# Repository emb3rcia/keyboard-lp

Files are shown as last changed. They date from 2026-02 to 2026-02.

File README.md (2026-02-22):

# keyboard-lp

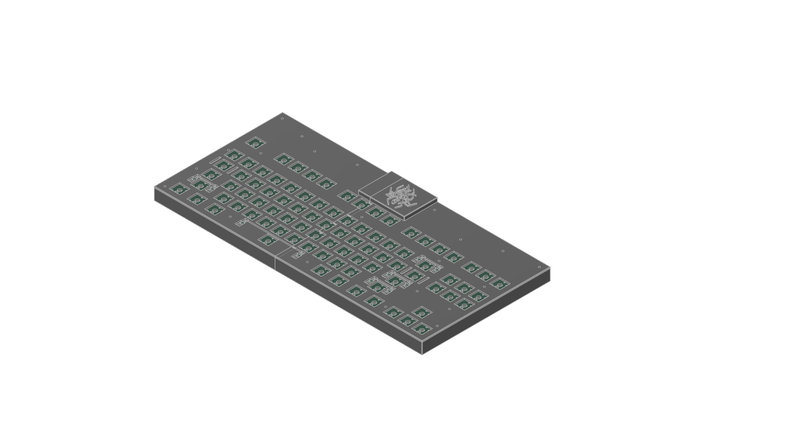
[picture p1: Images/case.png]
case


## Description

It is my first low-profile keyboard, and first per-key GPIO keyboard. It features 2 USB ports - one for communication with PC and one for power for LEDs, per-key LED backlight and full n-key rollover!

## Why i made this project

I like making keyboards, it is my second keyboard i designed and it is very fun. I also want to use LP keyboard, but i dont have budget to buy ready-to-use one.

## What i learned

Mainly i learned even more about tight connection layout on PCB, as with per-key GPIO i needed to connect each key to its individual pin on MCU.

# Photos

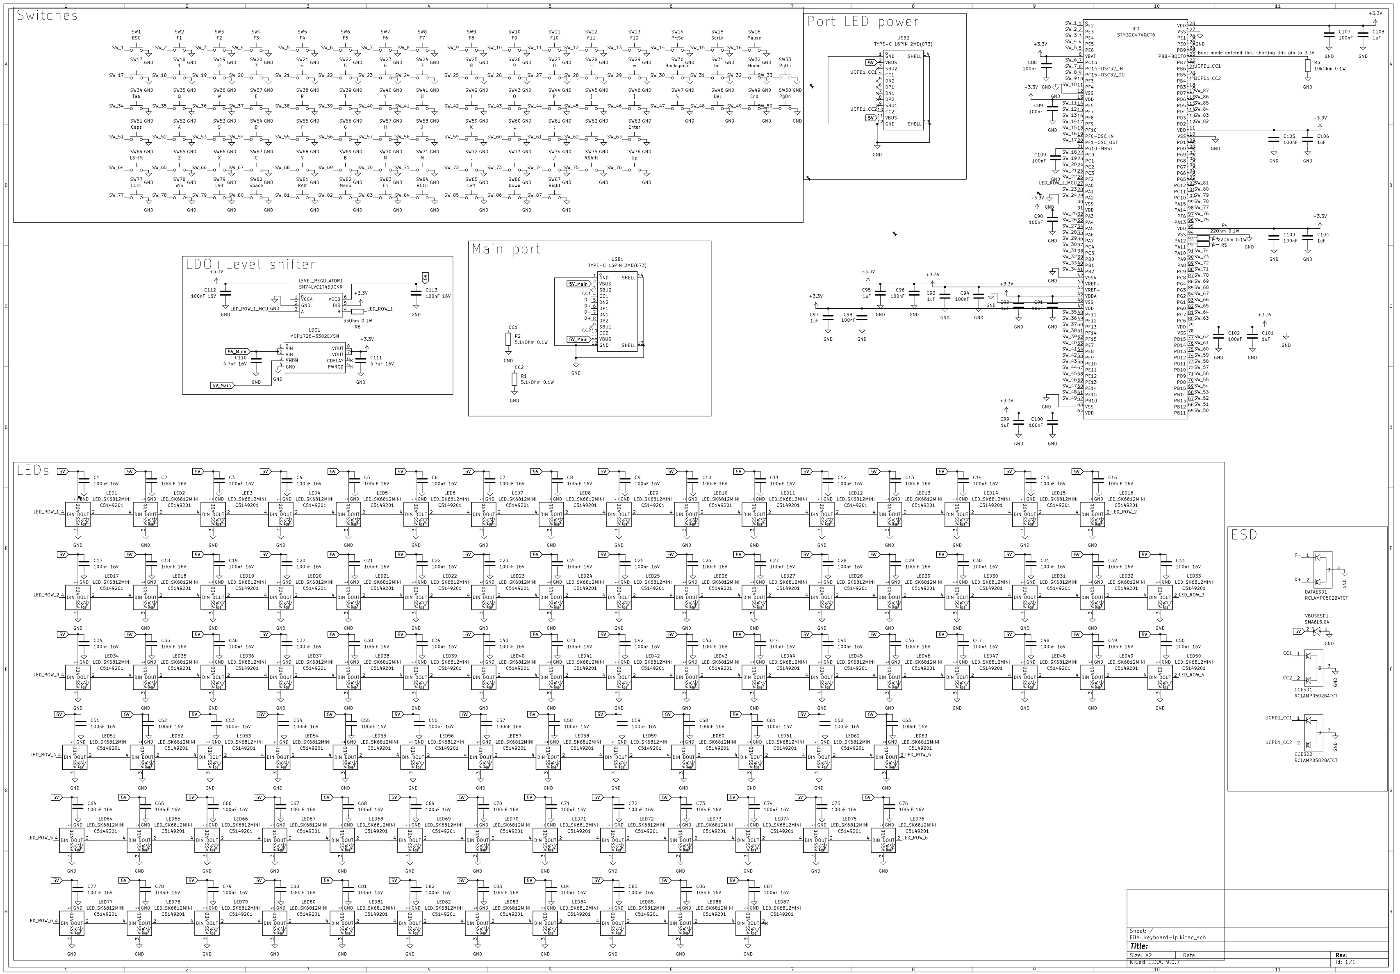
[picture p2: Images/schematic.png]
schematic


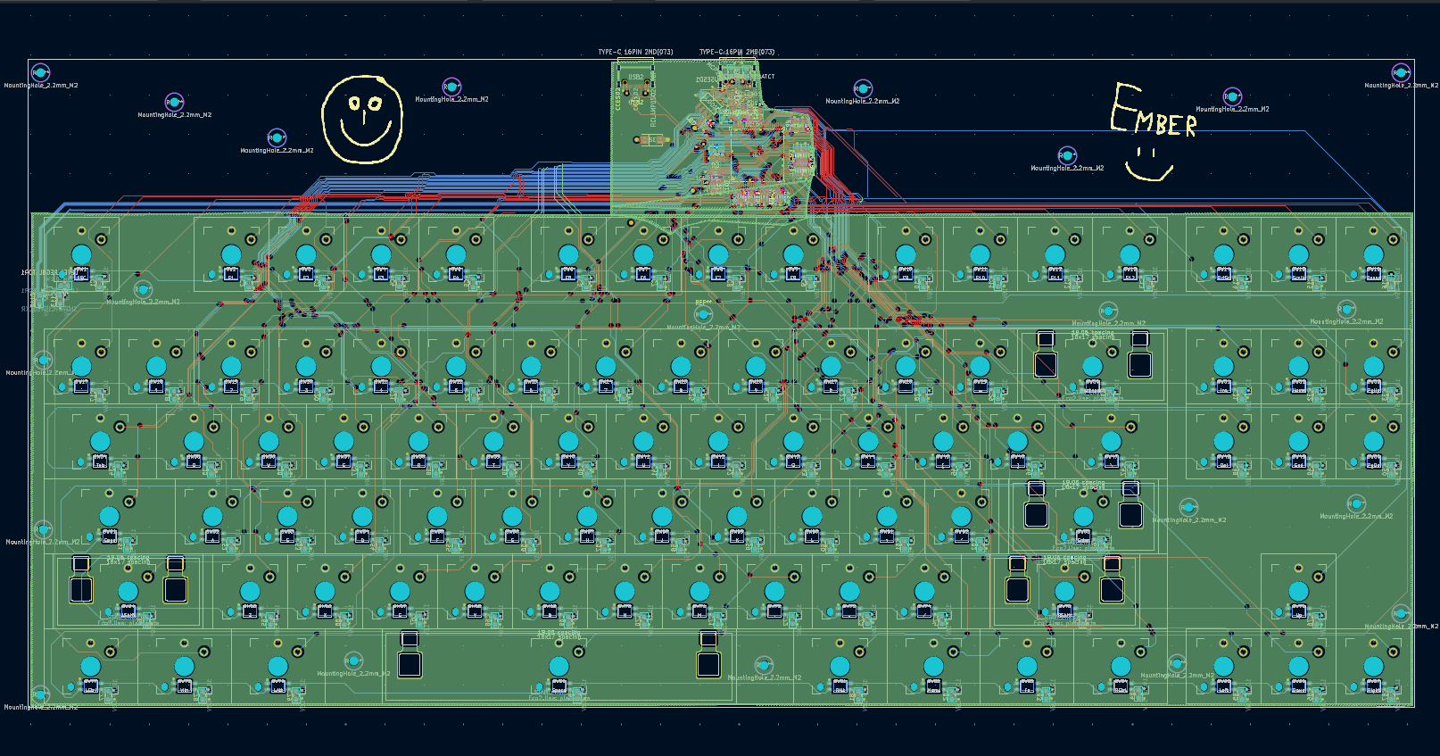
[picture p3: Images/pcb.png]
PCB


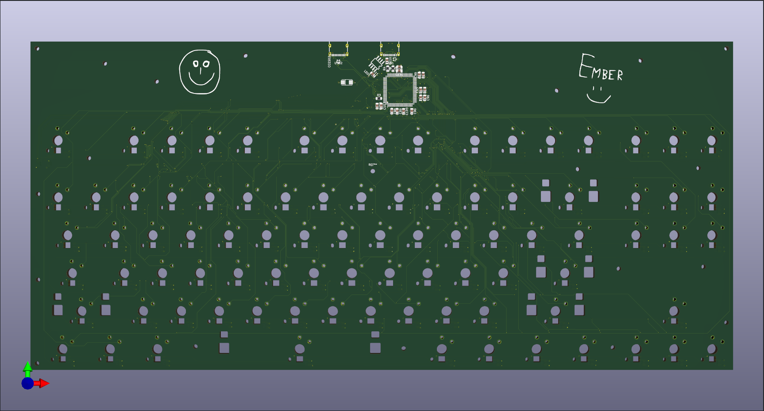
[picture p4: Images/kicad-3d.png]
kicad-3d


case

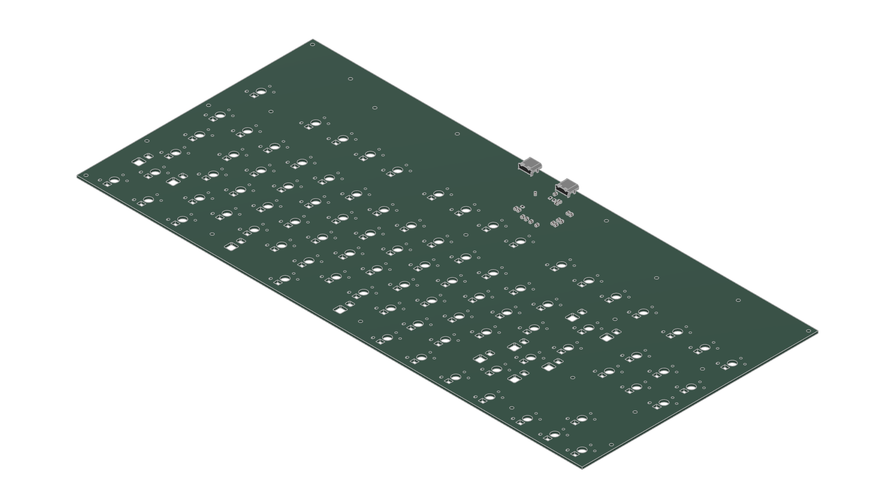
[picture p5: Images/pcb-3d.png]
pcb-3d


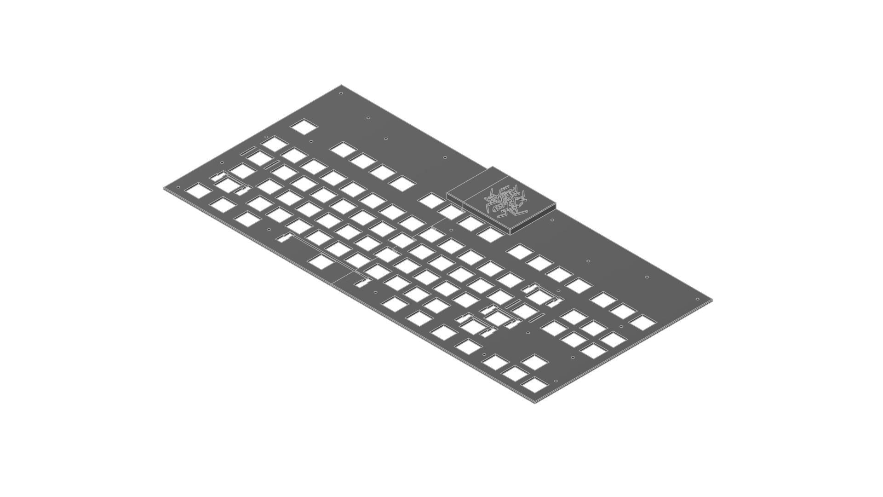
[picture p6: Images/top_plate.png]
top plate


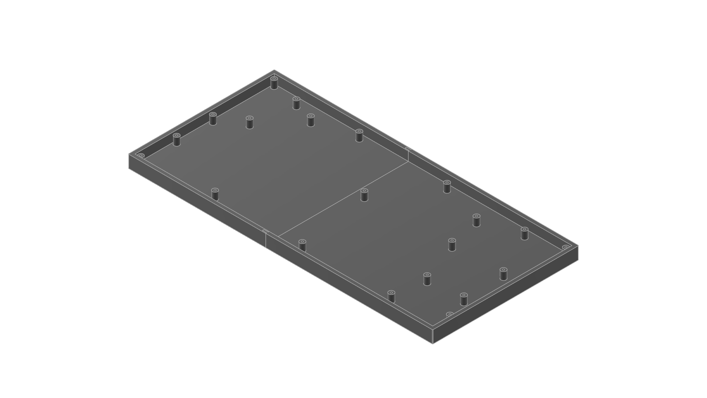
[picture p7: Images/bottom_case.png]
bottom case


# BOM

|Product |Description |Price |Shipping |Amount |Why more than needed |Link |
|---|---|---|---|---|---|---|
|Kalih Choc v2 |Switches |27.72USD|Free |90 |Nearest amount more to 87 needed |https://aliexpress.com/item/1005008175864256.html |
|Keycaps |Keycaps |14.89USD|Free |118 |Its full set, cheapest I could find|https://aliexpress.com/item/1005004613625285.html |
|Stabs |Stabilizers |6.10USD |Free |1x6.25u 4x2u|N/A |https://aliexpress.com/item/1005009331747192.html |
|TORCH C0805B104K500NT |Decoup caps |0.43USD |LCSC |125 |Sold in batches of 25, need 101 |https://www.lcsc.com/product-detail/C476766.html  |
|Taiyo Yuden HMK212BC7105KGHTE |Bigger decoup caps |0.43USD |LCSC |10 |Sold in batches of 10, need 9 |https://www.lcsc.com/product-detail/C385977.html  |
|KEMET C0805C473J3GECTU |Bulk decoup caps |1.04USD |LCSC |5 |Sold in batches of 5, need 2 |https://www.lcsc.com/product-detail/C22409503.html|
|TECH PUBLIC RCLAMP0502BATCT |ESD diode for CC and Data lanes|0.48USD |LCSC |10 |Sold in batches of 10, need 3 |https://www.lcsc.com/product-detail/C3040620.html |
|TI SN74LVC1T45DCKR |Level shifter |0.45USD |LCSC |5 |Sold in batches of 5, need 1 |https://www.lcsc.com/product-detail/C9382.html |
|SHOU HAN TYPE-C 16PIN 2MD(073) |USB-C ports |1.23USD |LCSC |20 |Sold in batches of 20, need 2 |https://www.lcsc.com/product-detail/C2765186.html |
|MICROCHIP MCP1726-3302E/SN |LDO |2.22USD |LCSC |1 |N/A |https://www.lcsc.com/product-detail/C635928.html  |
|OPSCO Optoelectronics SK6812MINI-YW|LED Diodes |14.85USD|LCSC |90 |Sold in batches of 5, need 87 |https://www.lcsc.com/product-detail/C5378722.html |
|Littelfuse SMA6L5.0A |VBUS ESD diodes |1.57USD |LCSC |2 |N/A |https://www.lcsc.com/product-detail/C1974860.html |
|FOJAN FRC0805J220 TS |Data lanes resistors |0.17USD |LCSC |100 |Sold in batches of 100, need 2 |https://www.lcsc.com/product-detail/C2907310.html |
|FOJAN FRC0805J330 TS |Level shifter→LEDs resistor |0.17USD |LCSC |100 |Sold in batches of 100, need 1 |https://www.lcsc.com/product-detail/C2907322.html |
|FOJAN FRC0805J103TS |Boot pin pulldown resistor |0.18USD |LCSC |100 |Sold in batches of 100, need 1 |https://www.lcsc.com/product-detail/C2930231.html |
|FOJAN FRC0805J512TS |CC resistors |0.17USD |LCSC |100 |Sold in batches of 100, need 2 |https://www.lcsc.com/product-detail/C2930296.html |
|ST STM32G474QCT6 |MCU |7.30USD |LCSC  (5.07USD for all items from LCSC)|1x6.25u 4x2u|N/A |https://www.lcsc.com/product-detail/C730128.html  |
|PCB from JLCPCB |PCB |54.40USD|19.14USD |5 |Minimal order is 5 |https://www.jlcpcb.com |
|Screws |M2x12 flathead screws |1.48USD |Free |50 |Minimal order is 50 |https://aliexpress.com/item/1005007593731439.html |
|Total |97.79USD |74.58USD|25.21USD | | | |

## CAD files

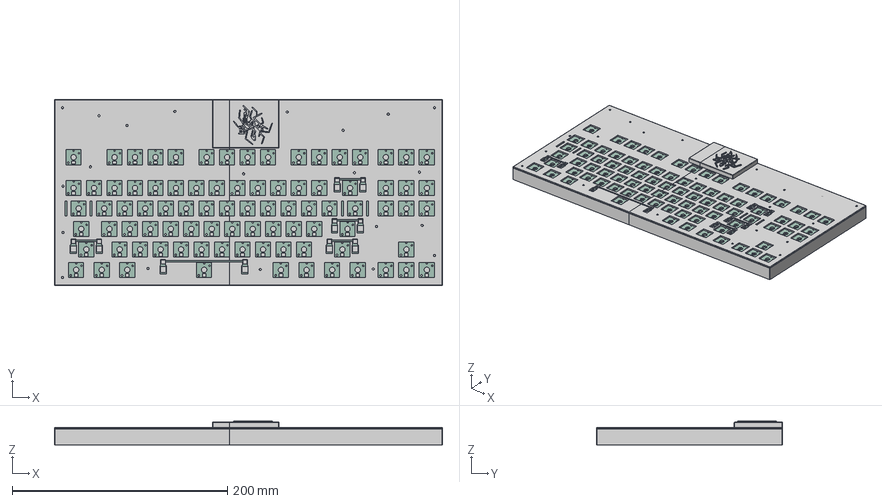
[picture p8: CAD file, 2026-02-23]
3D/step/case.step
360.9 x 173.0 x 22.2 mm
C_0805_2012Metric x 113
R_0805_2012Metric x 6
USB-C-SMD_TYPE-C-6PIN-2MD-073 x 2
keyboard-lp_PCB

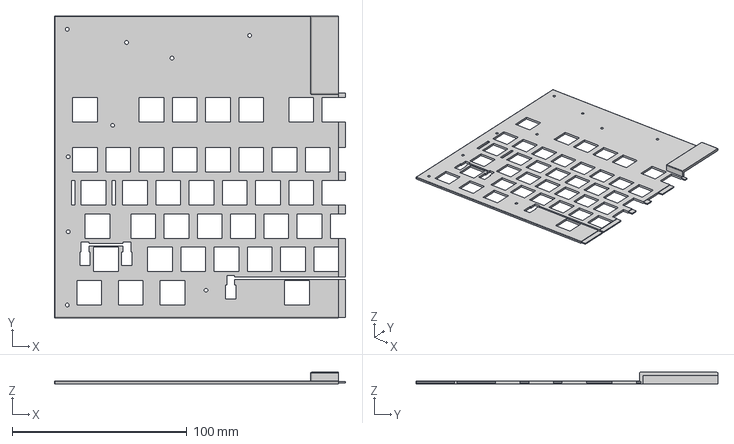
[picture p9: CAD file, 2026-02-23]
3D/step/top_plate_2.step
166.9 x 173.0 x 6.60 mm

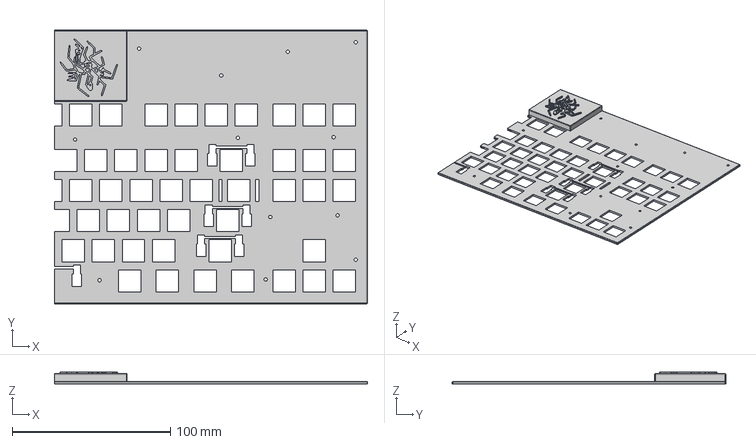
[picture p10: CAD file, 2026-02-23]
3D/step/top_plate_1.step
197.9 x 173.0 x 7.60 mm

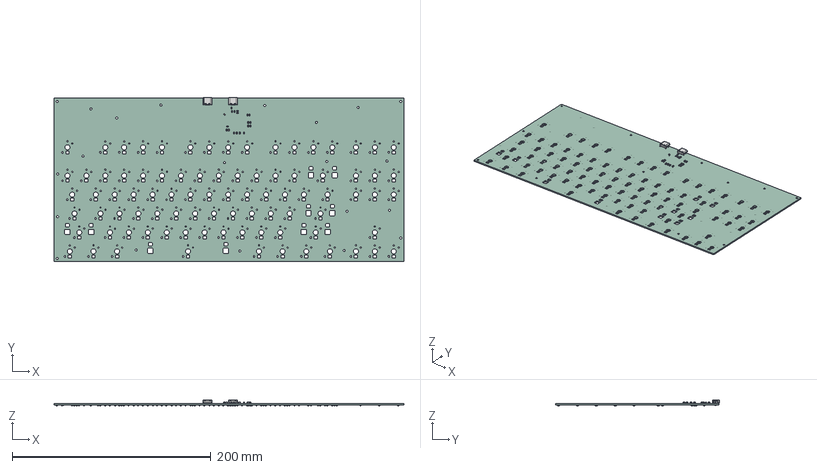
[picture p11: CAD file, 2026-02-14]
3D/step/pcb-3d.step
352.5 x 165.4 x 6.51 mm
C_0805_2012Metric x 113
R_0805_2012Metric x 6
USB-C-SMD_TYPE-C-6PIN-2MD-073 x 2
keyboard-lp_PCB

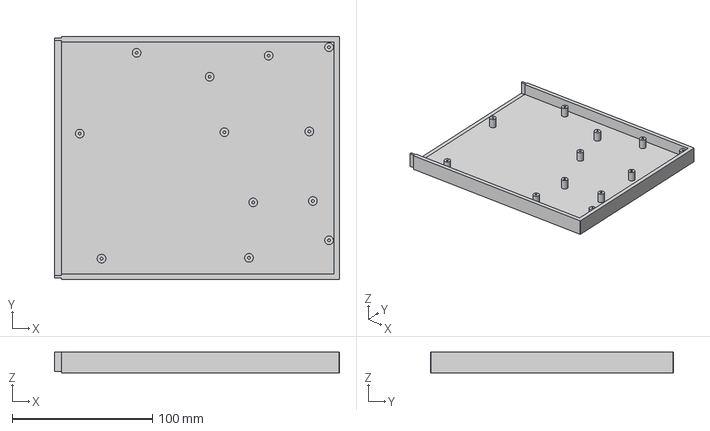
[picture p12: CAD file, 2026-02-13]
3D/step/bottom_case_1.step
202.9 x 173.0 x 14.6 mm

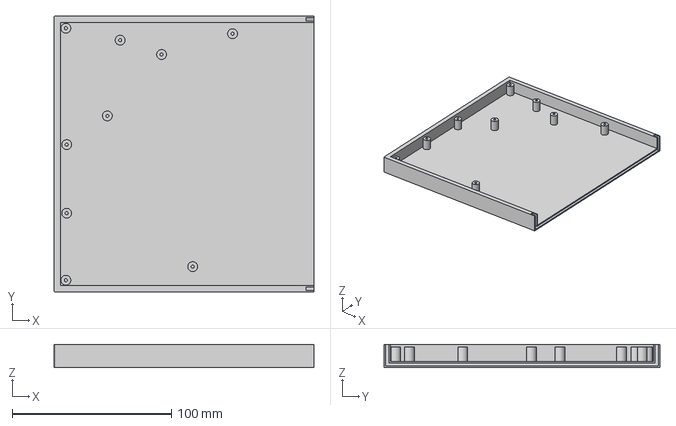
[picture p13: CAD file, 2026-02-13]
3D/step/bottom_case_2.step
162.9 x 173.0 x 14.6 mm

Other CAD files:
3D/f3d/bottom_case.f3d
3D/f3d/pcb-3d v2.f3d
3D/f3d/top_plate.f3d

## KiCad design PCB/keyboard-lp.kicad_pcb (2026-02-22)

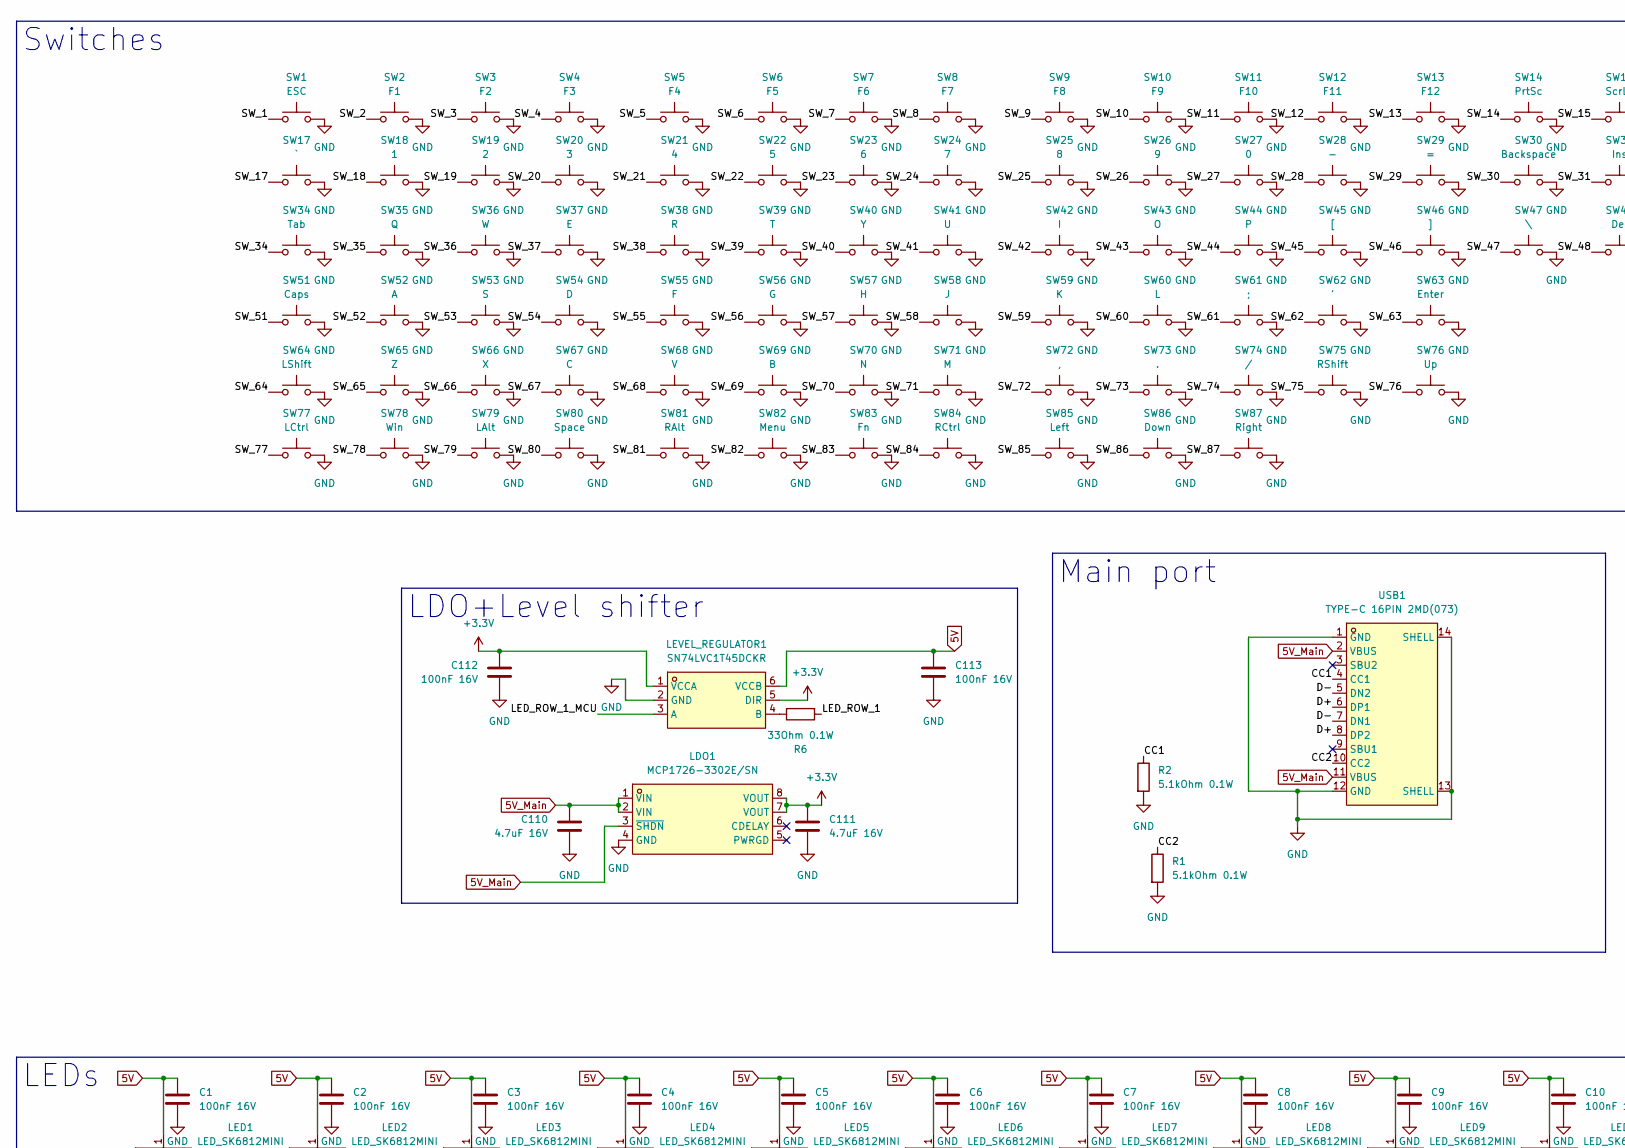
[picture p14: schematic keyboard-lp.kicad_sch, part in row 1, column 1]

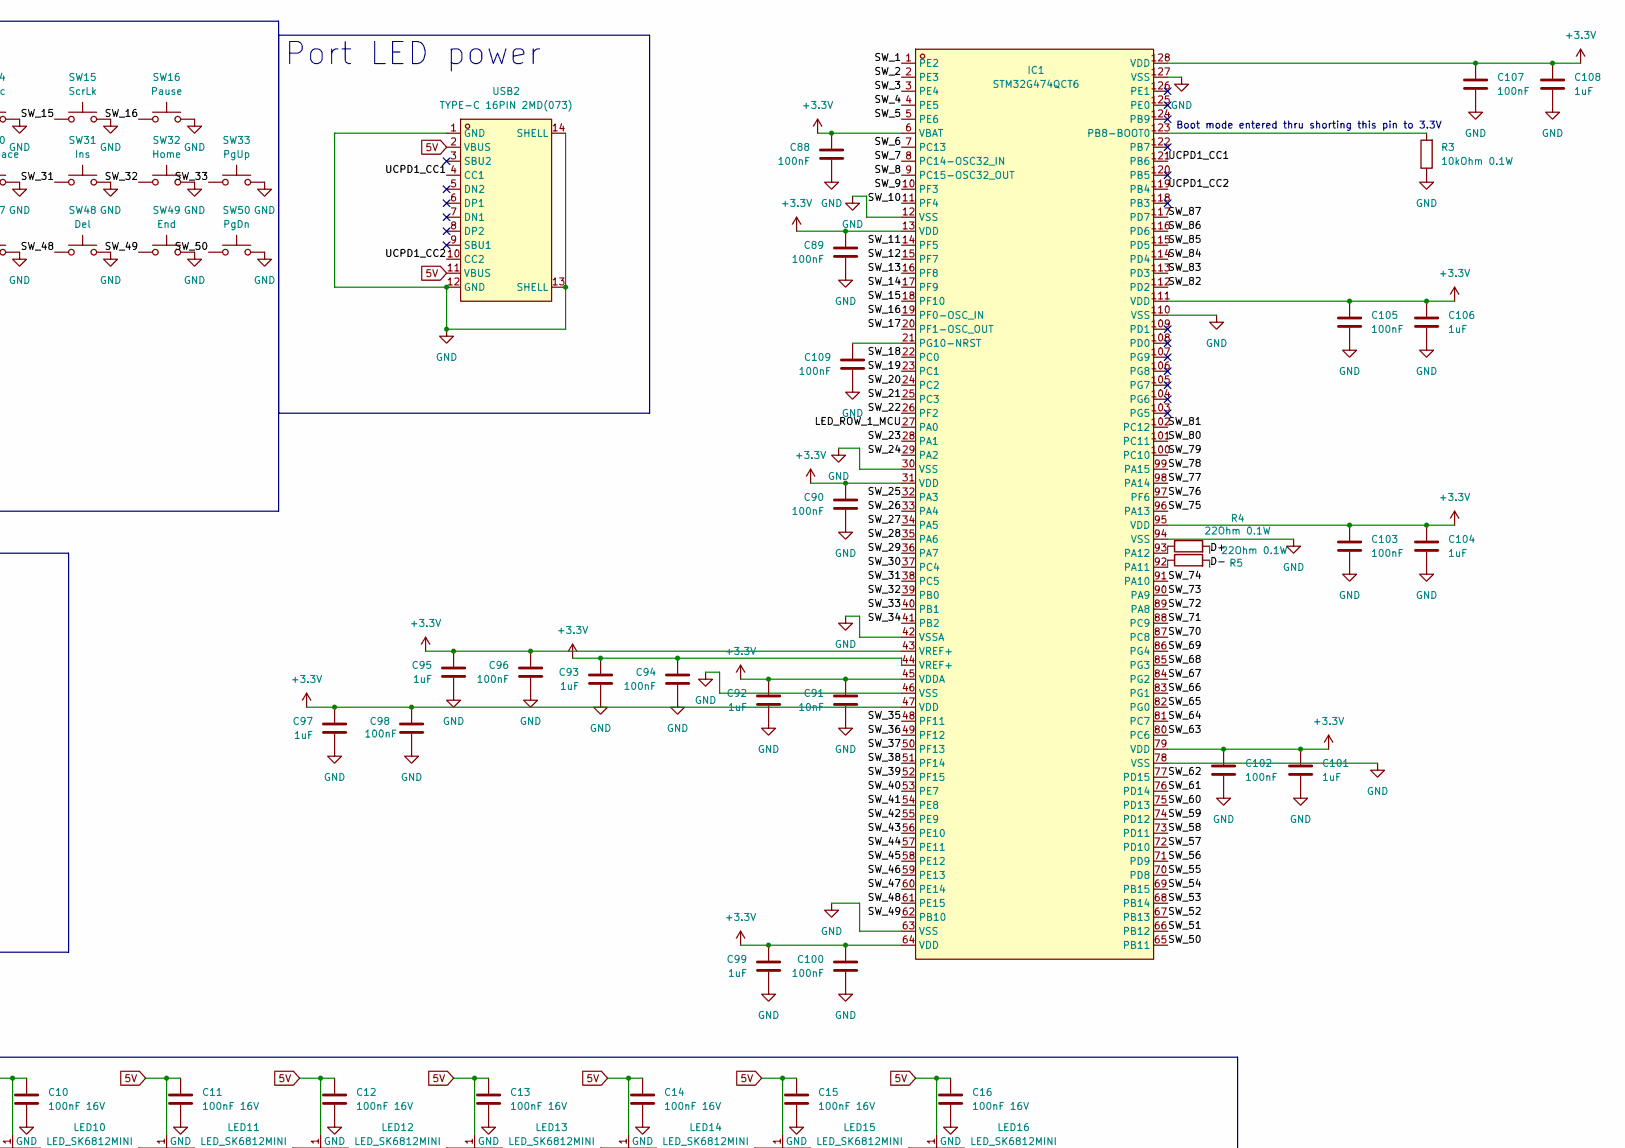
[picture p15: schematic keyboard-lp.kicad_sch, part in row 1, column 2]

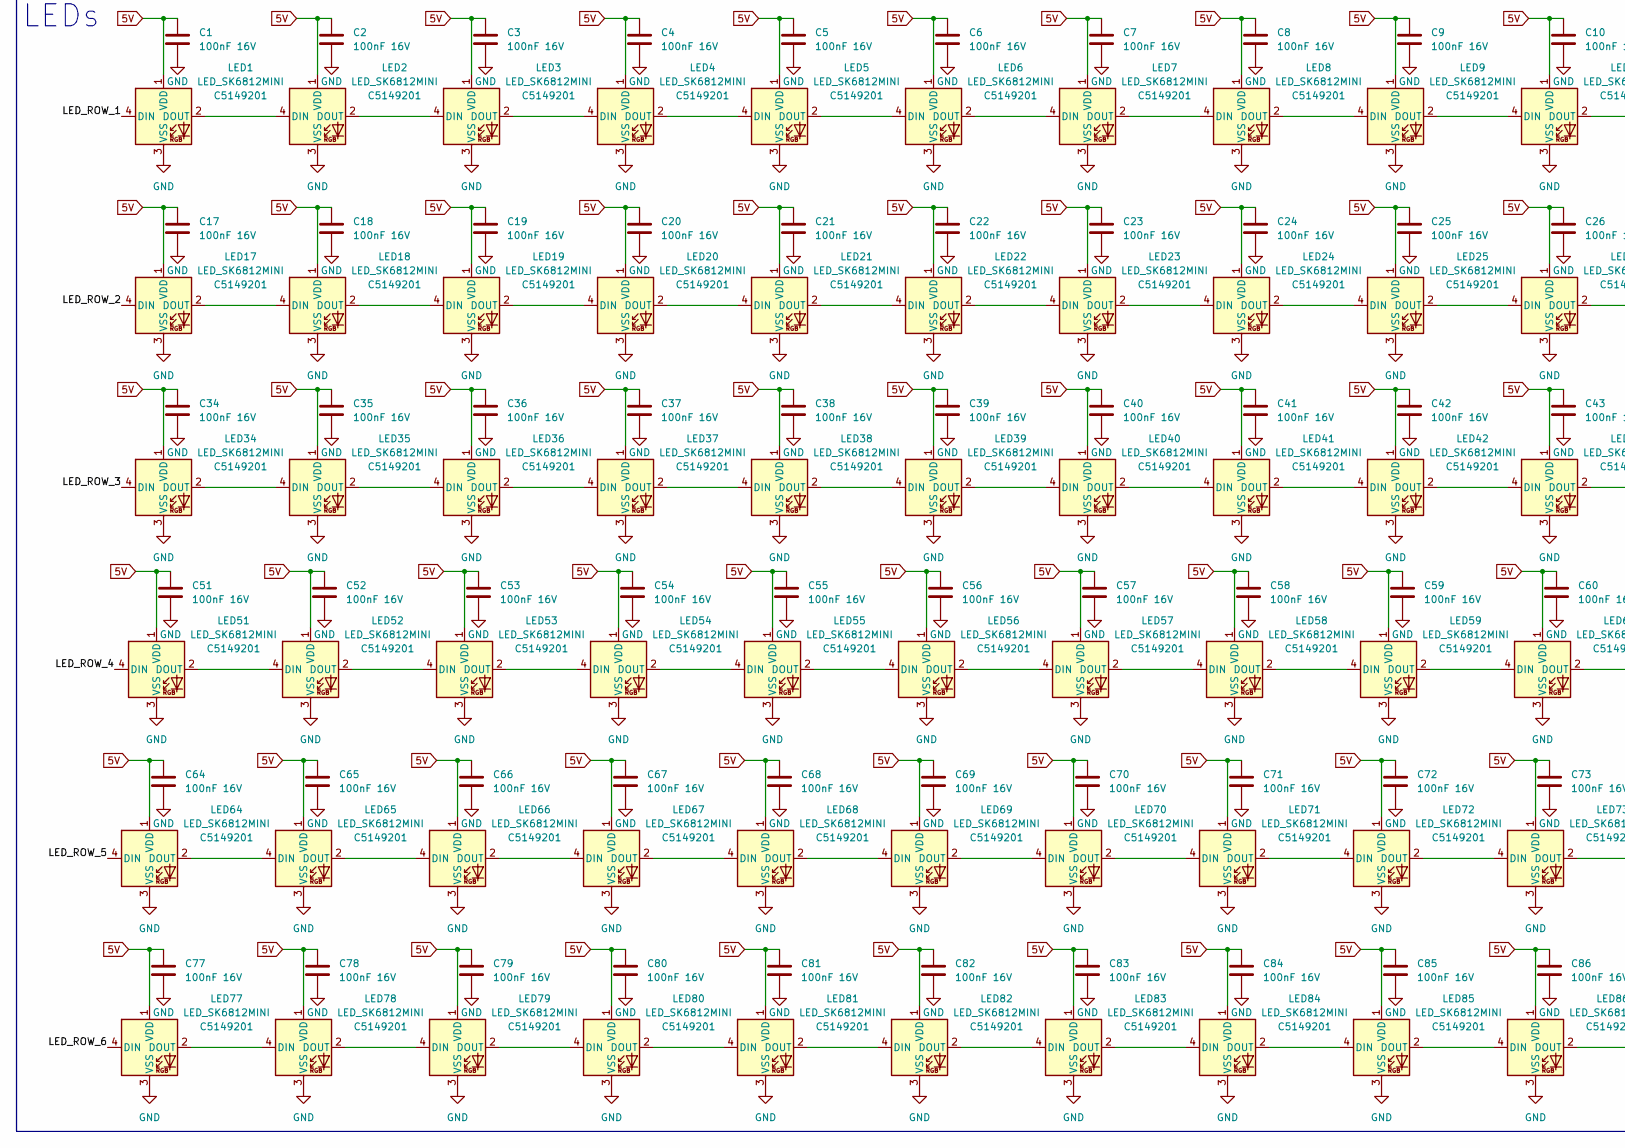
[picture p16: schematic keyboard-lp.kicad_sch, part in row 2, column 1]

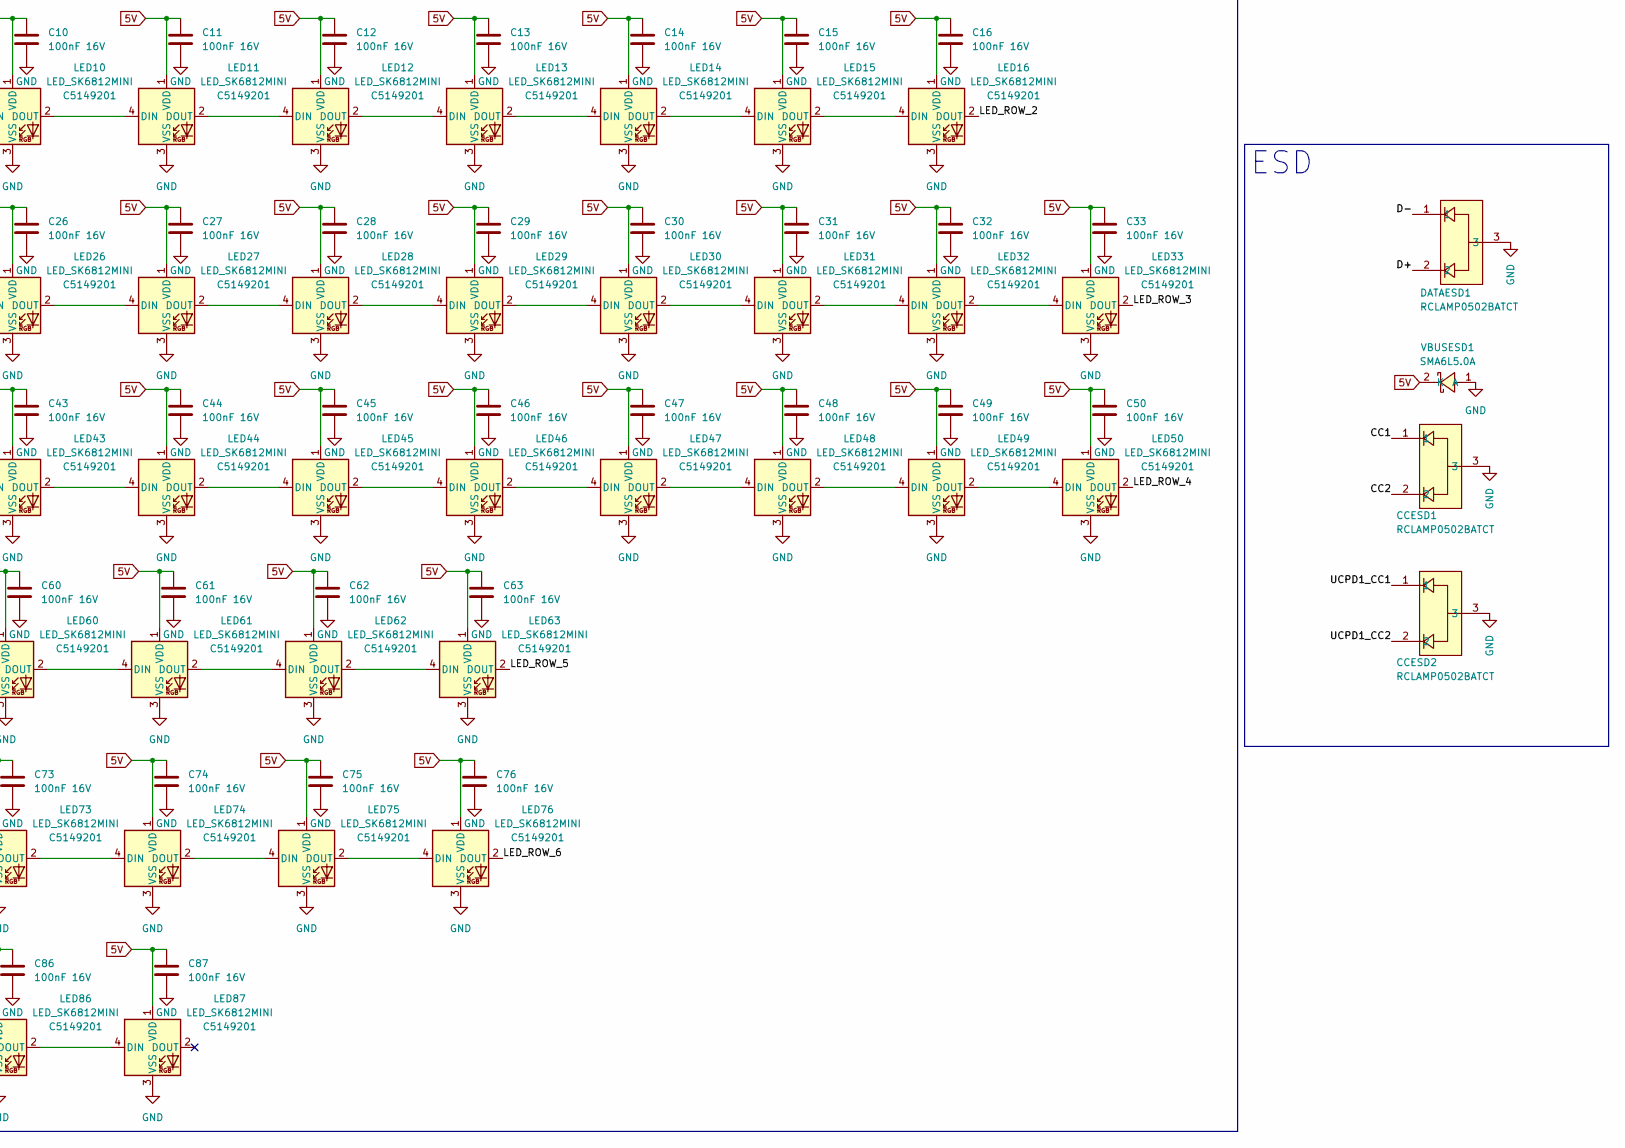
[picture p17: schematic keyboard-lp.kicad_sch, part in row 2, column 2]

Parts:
C1, C2, C3, C4, C5, C6, C7, C8, C9, C10, C11, C12, C13, C14, C15, C16, C17, C18, C19, C20, C21, C22, C23, C24, C25, C26, C27, C28, C29, C30, C31, C32, C33, C34, C35, C36, C37, C38, C39, C40, C41, C42, C43, C44, C45, C46, C47, C48, C49, C50, C51, C52, C53, C54, C55, C56, C57, C58, C59, C60, C61, C62, C63, C64, C65, C66, C67, C68, C69, C70, C71, C72, C73, C74, C75, C76, C77, C78, C79, C80, C81, C82, C83, C84, C85, C86, C87, C112, C113: 100nF 16V; C_0805_2012Metric_Pad1.18x1.45mm_HandSolder
C88, C89, C90, C94, C96, C98, C100, C102, C103, C105, C107, C109: 100nF; C_0805_2012Metric_Pad1.18x1.45mm_HandSolder
C91: 10nF; C_0805_2012Metric_Pad1.18x1.45mm_HandSolder
C92, C93, C95, C97, C99, C101, C104, C106, C108: 1uF; C_0805_2012Metric_Pad1.18x1.45mm_HandSolder
C110, C111: 4.7uF 16V; C_0805_2012Metric_Pad1.18x1.45mm_HandSolder
CCESD1, CCESD2: RCLAMP0502BATCT; SC-75-3_L1.6-W0.8-P1.00-LS1.6-BR; LCSC Part C117553
DATAESD1: RCLAMP0502BATCT; SC-75-3_L1.6-W0.8-P1.00-LS1.6-BR; LCSC Part C117553
IC1: STM32G474QCT6; LQFP-128_L14.0-W14.0-P0.40-LS16.0-BL; LCSC Part C730128
LDO1: MCP1726-3302E/SN; SOIC-8_L5.0-W4.0-P1.27-LS6.1-BL; LCSC Part C635928
LED1, LED2, LED3, LED4, LED5, LED6, LED7, LED8, LED9, LED10, LED11, LED12, LED13, LED14, LED15, LED16, LED17, LED18, LED19, LED20, LED21, LED22, LED23, LED24, LED25, LED26, LED27, LED28, LED29, LED30, LED31, LED32, LED33, LED34, LED35, LED36, LED37, LED38, LED39, LED40, LED41, LED42, LED43, LED44, LED45, LED46, LED47, LED48, LED49, LED50, LED51, LED52, LED53, LED54, LED55, LED56, LED57, LED58, LED59, LED60, LED61, LED62, LED63, LED64, LED65, LED66, LED67, LED68, LED69, LED70, LED71, LED72, LED73, LED74, LED75, LED76, LED77, LED78, LED79, LED80, LED81, LED82, LED83, LED84, LED85, LED86, LED87: LED_SK6812MINI; LCSC C5149201
LEVEL_REGULATOR1: SN74LVC1T45DCKR; SC-70-6_L2.2-W1.3-P0.65-LS2.2-BR; LCSC Part C9382
R1, R2: 5.1kOhm 0.1W; R_0805_2012Metric_Pad1.20x1.40mm_HandSolder
R3: 10kOhm 0.1W; R_0805_2012Metric_Pad1.20x1.40mm_HandSolder
R4, R5: 22Ohm 0.1W; R_0805_2012Metric_Pad1.20x1.40mm_HandSolder
R6: 33Ohm 0.1W; R_0805_2012Metric_Pad1.20x1.40mm_HandSolder
SW1: ESC; Kailh-PG1353-Solderable-1U
SW2: F1; Kailh-PG1353-Solderable-1U
SW3: F2; Kailh-PG1353-Solderable-1U
SW4: F3; Kailh-PG1353-Solderable-1U
SW5: F4; Kailh-PG1353-Solderable-1U
SW6: F5; Kailh-PG1353-Solderable-1U
SW7: F6; Kailh-PG1353-Solderable-1U
SW8: F7; Kailh-PG1353-Solderable-1U
SW9: F8; Kailh-PG1353-Solderable-1U
SW10: F9; Kailh-PG1353-Solderable-1U
SW11: F10; Kailh-PG1353-Solderable-1U
SW12: F11; Kailh-PG1353-Solderable-1U
SW13: F12; Kailh-PG1353-Solderable-1U
SW14: PrtSc; Kailh-PG1353-Solderable-1U
SW15: ScrLk; Kailh-PG1353-Solderable-1U
SW16: Pause; Kailh-PG1353-Solderable-1U
SW17: `; Kailh-PG1353-Solderable-1U
SW18: 1; Kailh-PG1353-Solderable-1U
SW19: 2; Kailh-PG1353-Solderable-1U
SW20: 3; Kailh-PG1353-Solderable-1U
SW21: 4; Kailh-PG1353-Solderable-1U
SW22: 5; Kailh-PG1353-Solderable-1U
SW23: 6; Kailh-PG1353-Solderable-1U
SW24: 7; Kailh-PG1353-Solderable-1U
SW25: 8; Kailh-PG1353-Solderable-1U
SW26: 9; Kailh-PG1353-Solderable-1U
SW27: 0; Kailh-PG1353-Solderable-1U
SW28: -; Kailh-PG1353-Solderable-1U
SW29: =; Kailh-PG1353-Solderable-1U
SW30: Backspace; Kailh-PG1353-Solderable-2U
SW31: Ins; Kailh-PG1353-Solderable-1U
SW32: Home; Kailh-PG1353-Solderable-1U
SW33: PgUp; Kailh-PG1353-Solderable-1U
SW34: Tab; Kailh-PG1353-Solderable-1.5U
SW35: Q; Kailh-PG1353-Solderable-1U
SW36: W; Kailh-PG1353-Solderable-1U
SW37: E; Kailh-PG1353-Solderable-1U
SW38: R; Kailh-PG1353-Solderable-1U
SW39: T; Kailh-PG1353-Solderable-1U
SW40: Y; Kailh-PG1353-Solderable-1U
SW41: U; Kailh-PG1353-Solderable-1U
SW42: I; Kailh-PG1353-Solderable-1U
SW43: O; Kailh-PG1353-Solderable-1U
SW44: P; Kailh-PG1353-Solderable-1U
SW45: [; Kailh-PG1353-Solderable-1U
SW46: ]; Kailh-PG1353-Solderable-1U
SW47: \; Kailh-PG1353-Solderable-1.5U
SW48: Del; Kailh-PG1353-Solderable-1U
SW49: End; Kailh-PG1353-Solderable-1U
SW50: PgDn; Kailh-PG1353-Solderable-1U
SW51: Caps; Kailh-PG1353-Solderable-1.75U
SW52: A; Kailh-PG1353-Solderable-1U
SW53: S; Kailh-PG1353-Solderable-1U
SW54: D; Kailh-PG1353-Solderable-1U
SW55: F; Kailh-PG1353-Solderable-1U
SW56: G; Kailh-PG1353-Solderable-1U
SW57: H; Kailh-PG1353-Solderable-1U
SW58: J; Kailh-PG1353-Solderable-1U
SW59: K; Kailh-PG1353-Solderable-1U
SW60: L; Kailh-PG1353-Solderable-1U
SW61: ;; Kailh-PG1353-Solderable-1U
SW62: '; Kailh-PG1353-Solderable-1U
SW63: Enter; Kailh-PG1353-Solderable-2.25U
SW64: LShift; Kailh-PG1353-Solderable-2.25U
SW65: Z; Kailh-PG1353-Solderable-1U
SW66: X; Kailh-PG1353-Solderable-1U
SW67: C; Kailh-PG1353-Solderable-1U
SW68: V; Kailh-PG1353-Solderable-1U
SW69: B; Kailh-PG1353-Solderable-1U
SW70: N; Kailh-PG1353-Solderable-1U
SW71: M; Kailh-PG1353-Solderable-1U
SW72: ,; Kailh-PG1353-Solderable-1U
SW73: .; Kailh-PG1353-Solderable-1U
SW74: /; Kailh-PG1353-Solderable-1U
SW75: RShift; Kailh-PG1353-Solderable-2.75U
SW76: Up; Kailh-PG1353-Solderable-1U
SW77: LCtrl; Kailh-PG1353-Solderable-1.25U
SW78: Win; Kailh-PG1353-Solderable-1.25U
SW79: LAlt; Kailh-PG1353-Solderable-1.25U
SW80: Space; Kailh-PG1353-Solderable-6.25U
SW81: RAlt; Kailh-PG1353-Solderable-1.25U
SW82: Menu; Kailh-PG1353-Solderable-1.25U
SW83: Fn; Kailh-PG1353-Solderable-1.25U
SW84: RCtrl; Kailh-PG1353-Solderable-1.25U
SW85: Left; Kailh-PG1353-Solderable-1U
SW86: Down; Kailh-PG1353-Solderable-1U
SW87: Right; Kailh-PG1353-Solderable-1U
USB1, USB2: TYPE-C 16PIN 2MD(073); USB-C-SMD_TYPE-C-6PIN-2MD-073; LCSC Part C2765186
VBUSESD1: SMA6L5.0A; SMA_L4.3-W2.6-LS5.2-R-RD; LCSC Part C1974860

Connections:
+3.3V: C88.1, C89.1, C90.1, C91.1, C92.1, C93.1, C94.1, C95.1, C96.1, C97.1, C98.1, C99.1, C100.1, C101.1, C102.1, C103.1, C104.1, C105.1, C106.1, C107.1, C108.1, C111.1, C112.1, IC1.6 (VBAT), IC1.13 (VDD), IC1.31 (VDD), IC1.43 (VREF+), IC1.44 (VREF+), IC1.45 (VDDA), IC1.47 (VDD), IC1.64 (VDD), IC1.79 (VDD), IC1.95 (VDD), IC1.111 (VDD), IC1.128 (VDD), LDO1.7 (VOUT), LDO1.8 (VOUT), LEVEL_REGULATOR1.1 (VCCA), LEVEL_REGULATOR1.5 (DIR)
/CC1: CCESD1.1, R2.1, USB1.4 (CC1)
/CC2: CCESD1.2, R1.1, USB1.10 (CC2)
/D+: DATAESD1.2, R4.2, USB1.6 (DP1), USB1.8 (DP2)
/D-: DATAESD1.1, R5.2, USB1.5 (DN2), USB1.7 (DN1)
/LED_ROW_1: LED1.4 (DIN), R6.2
/LED_ROW_1_MCU: IC1.27 (PA0), LEVEL_REGULATOR1.3 (A)
/LED_ROW_2: LED16.2 (DOUT), LED17.4 (DIN)
/LED_ROW_3: LED33.2 (DOUT), LED34.4 (DIN)
/LED_ROW_4: LED50.2 (DOUT), LED51.4 (DIN)
/LED_ROW_5: LED63.2 (DOUT), LED64.4 (DIN)
/LED_ROW_6: LED76.2 (DOUT), LED77.4 (DIN)
/SW_1: IC1.1 (PE2), SW1.1
/SW_2: IC1.2 (PE3), SW2.1
/SW_3: IC1.3 (PE4), SW3.1
/SW_4: IC1.4 (PE5), SW4.1
/SW_5: IC1.5 (PE6), SW5.1
/SW_6: IC1.7 (PC13), SW6.1
/SW_7: IC1.8 (PC14-OSC32_IN), SW7.1
/SW_8: IC1.9 (PC15-OSC32_OUT), SW8.1
/SW_9: IC1.10 (PF3), SW9.1
/SW_10: IC1.11 (PF4), SW10.1
/SW_11: IC1.14 (PF5), SW11.1
/SW_12: IC1.15 (PF7), SW12.1
/SW_13: IC1.16 (PF8), SW13.1
/SW_14: IC1.17 (PF9), SW14.1
/SW_15: IC1.18 (PF10), SW15.1
/SW_16: IC1.19 (PF0-OSC_IN), SW16.1
/SW_17: IC1.20 (PF1-OSC_OUT), SW17.1
/SW_18: IC1.22 (PC0), SW18.1
/SW_19: IC1.23 (PC1), SW19.1
/SW_20: IC1.24 (PC2), SW20.1
/SW_21: IC1.25 (PC3), SW21.1
/SW_22: IC1.26 (PF2), SW22.1
/SW_23: IC1.28 (PA1), SW23.1
/SW_24: IC1.29 (PA2), SW24.1
/SW_25: IC1.32 (PA3), SW25.1
/SW_26: IC1.33 (PA4), SW26.1
/SW_27: IC1.34 (PA5), SW27.1
/SW_28: IC1.35 (PA6), SW28.1
/SW_29: IC1.36 (PA7), SW29.1
/SW_30: IC1.37 (PC4), SW30.1
/SW_31: IC1.38 (PC5), SW31.1
/SW_32: IC1.39 (PB0), SW32.1
/SW_33: IC1.40 (PB1), SW33.1
/SW_34: IC1.41 (PB2), SW34.1
/SW_35: IC1.48 (PF11), SW35.1
/SW_36: IC1.49 (PF12), SW36.1
/SW_37: IC1.50 (PF13), SW37.1
/SW_38: IC1.51 (PF14), SW38.1
/SW_39: IC1.52 (PF15), SW39.1
/SW_40: IC1.53 (PE7), SW40.1
/SW_41: IC1.54 (PE8), SW41.1
/SW_42: IC1.55 (PE9), SW42.1
/SW_43: IC1.56 (PE10), SW43.1
/SW_44: IC1.57 (PE11), SW44.1
/SW_45: IC1.58 (PE12), SW45.1
/SW_46: IC1.59 (PE13), SW46.1
/SW_47: IC1.60 (PE14), SW47.1
/SW_48: IC1.61 (PE15), SW48.1
/SW_49: IC1.62 (PB10), SW49.1
/SW_50: IC1.65 (PB11), SW50.1
/SW_51: IC1.66 (PB12), SW51.1
/SW_52: IC1.67 (PB13), SW52.1
/SW_53: IC1.68 (PB14), SW53.1
/SW_54: IC1.69 (PB15), SW54.1
/SW_55: IC1.70 (PD8), SW55.1
/SW_56: IC1.71 (PD9), SW56.1
/SW_57: IC1.72 (PD10), SW57.1
/SW_58: IC1.73 (PD11), SW58.1
/SW_59: IC1.74 (PD12), SW59.1
/SW_60: IC1.75 (PD13), SW60.1
/SW_61: IC1.76 (PD14), SW61.1
/SW_62: IC1.77 (PD15), SW62.1
/SW_63: IC1.80 (PC6), SW63.1
/SW_64: IC1.81 (PC7), SW64.1
/SW_65: IC1.82 (PG0), SW65.1
/SW_66: IC1.83 (PG1), SW66.1
/SW_67: IC1.84 (PG2), SW67.1
/SW_68: IC1.85 (PG3), SW68.1
/SW_69: IC1.86 (PG4), SW69.1
/SW_70: IC1.87 (PC8), SW70.1
/SW_71: IC1.88 (PC9), SW71.1
/SW_72: IC1.89 (PA8), SW72.1
/SW_73: IC1.90 (PA9), SW73.1
/SW_74: IC1.91 (PA10), SW74.1
/SW_75: IC1.96 (PA13), SW75.1
/SW_76: IC1.97 (PF6), SW76.1
/SW_77: IC1.98 (PA14), SW77.1
/SW_78: IC1.99 (PA15), SW78.1
/SW_79: IC1.100 (PC10), SW79.1
/SW_80: IC1.101 (PC11), SW80.1
/SW_81: IC1.102 (PC12), SW81.1
/SW_82: IC1.112 (PD2), SW82.1
/SW_83: IC1.113 (PD3), SW83.1
/SW_84: IC1.114 (PD4), SW84.1
/SW_85: IC1.115 (PD5), SW85.1
/SW_86: IC1.116 (PD6), SW86.1
/SW_87: IC1.117 (PD7), SW87.1
/UCPD1_CC1: CCESD2.1, IC1.121 (PB6), USB2.4 (CC1)
/UCPD1_CC2: CCESD2.2, IC1.119 (PB4), USB2.10 (CC2)
GND: C1.2, C2.2, C3.2, C4.2, C5.2, C6.2, C7.2, C8.2, C9.2, C10.2, C11.2, C12.2, C13.2, C14.2, C15.2, C16.2, C17.2, C18.2, C19.2, C20.2, C21.2, C22.2, C23.2, C24.2, C25.2, C26.2, C27.2, C28.2, C29.2, C30.2, C31.2, C32.2, C33.2, C34.2, C35.2, C36.2, C37.2, C38.2, C39.2, C40.2, C41.2, C42.2, C43.2, C44.2, C45.2, C46.2, C47.2, C48.2, C49.2, C50.2, C51.2, C52.2, C53.2, C54.2, C55.2, C56.2, C57.2, C58.2, C59.2, C60.2, C61.2, C62.2, C63.2, C64.2, C65.2, C66.2, C67.2, C68.2, C69.2, C70.2, C71.2, C72.2, C73.2, C74.2, C75.2, C76.2, C77.2, C78.2, C79.2, C80.2, C81.2, C82.2, C83.2, C84.2, C85.2, C86.2, C87.2, C88.2, C89.2, C90.2, C91.2, C92.2, C93.2, C94.2, C95.2, C96.2, C97.2, C98.2, C99.2, C100.2, C101.2, C102.2, C103.2, C104.2, C105.2, C106.2, C107.2, C108.2, C109.2, C110.2, C111.2, C112.2, C113.2, CCESD1.3, CCESD2.3, DATAESD1.3, IC1.12 (VSS), IC1.30 (VSS), IC1.42 (VSSA), IC1.46 (VSS), IC1.63 (VSS), IC1.78 (VSS), IC1.94 (VSS), IC1.110 (VSS), IC1.127 (VSS), LDO1.4 (GND), LED1.3 (VSS), LED2.3 (VSS), LED3.3 (VSS), LED4.3 (VSS), LED5.3 (VSS), LED6.3 (VSS), LED7.3 (VSS), LED8.3 (VSS), LED9.3 (VSS), LED10.3 (VSS), LED11.3 (VSS), LED12.3 (VSS), LED13.3 (VSS), LED14.3 (VSS), LED15.3 (VSS), LED16.3 (VSS), LED17.3 (VSS), LED18.3 (VSS), LED19.3 (VSS), LED20.3 (VSS), LED21.3 (VSS), LED22.3 (VSS), LED23.3 (VSS), LED24.3 (VSS), LED25.3 (VSS), LED26.3 (VSS), LED27.3 (VSS), LED28.3 (VSS), LED29.3 (VSS), LED30.3 (VSS), LED31.3 (VSS), LED32.3 (VSS), LED33.3 (VSS), LED34.3 (VSS), LED35.3 (VSS), LED36.3 (VSS), LED37.3 (VSS), LED38.3 (VSS), LED39.3 (VSS), LED40.3 (VSS), LED41.3 (VSS), LED42.3 (VSS), LED43.3 (VSS), LED44.3 (VSS), LED45.3 (VSS), LED46.3 (VSS), LED47.3 (VSS), LED48.3 (VSS), LED49.3 (VSS), LED50.3 (VSS), LED51.3 (VSS), LED52.3 (VSS), LED53.3 (VSS), LED54.3 (VSS), LED55.3 (VSS), LED56.3 (VSS), LED57.3 (VSS), LED58.3 (VSS), LED59.3 (VSS), LED60.3 (VSS), LED61.3 (VSS), LED62.3 (VSS), LED63.3 (VSS), LED64.3 (VSS), LED65.3 (VSS), LED66.3 (VSS), LED67.3 (VSS), LED68.3 (VSS), LED69.3 (VSS), LED70.3 (VSS), LED71.3 (VSS), LED72.3 (VSS), LED73.3 (VSS), LED74.3 (VSS), LED75.3 (VSS), LED76.3 (VSS), LED77.3 (VSS), LED78.3 (VSS), LED79.3 (VSS), LED80.3 (VSS), LED81.3 (VSS), LED82.3 (VSS), LED83.3 (VSS), LED84.3 (VSS), LED85.3 (VSS), LED86.3 (VSS), LED87.3 (VSS), LEVEL_REGULATOR1.2 (GND), R1.2, R2.2, R3.1, SW1.2, SW2.2, SW3.2, SW4.2, SW5.2, SW6.2, SW7.2, SW8.2, SW9.2, SW10.2, SW11.2, SW12.2, SW13.2, SW14.2, SW15.2, SW16.2, SW17.2, SW18.2, SW19.2, SW20.2, SW21.2, SW22.2, SW23.2, SW24.2, SW25.2, SW26.2, SW27.2, SW28.2, SW29.2, SW30.2, SW31.2, SW32.2, SW33.2, SW34.2, SW35.2, SW36.2, SW37.2, SW38.2, SW39.2, SW40.2, SW41.2, SW42.2, SW43.2, SW44.2, SW45.2, SW46.2, SW47.2, SW48.2, SW49.2, SW50.2, SW51.2, SW52.2, SW53.2, SW54.2, SW55.2, SW56.2, SW57.2, SW58.2, SW59.2, SW60.2, SW61.2, SW62.2, SW63.2, SW64.2, SW65.2, SW66.2, SW67.2, SW68.2, SW69.2, SW70.2, SW71.2, SW72.2, SW73.2, SW74.2, SW75.2, SW76.2, SW77.2, SW78.2, SW79.2, SW80.2, SW81.2, SW82.2, SW83.2, SW84.2, SW85.2, SW86.2, SW87.2, USB1.1 (GND), USB1.12 (GND), USB1.13 (SHELL), USB1.14 (SHELL), USB2.1 (GND), USB2.12 (GND), USB2.13 (SHELL), USB2.14 (SHELL), VBUSESD1.1 (A); also elsewhere on the board
unnamed: IC1.92 (PA11), R5.1
unnamed: IC1.93 (PA12), R4.1
unnamed: IC1.123 (PB8-BOOT0), R3.2
unnamed: C109.1, IC1.21 (PG10-NRST)
unnamed: LED1.2 (DOUT), LED2.4 (DIN)
unnamed: LED2.2 (DOUT), LED3.4 (DIN)
unnamed: LED3.2 (DOUT), LED4.4 (DIN)
unnamed: LED4.2 (DOUT), LED5.4 (DIN)
unnamed: LED5.2 (DOUT), LED6.4 (DIN)
unnamed: LED6.2 (DOUT), LED7.4 (DIN)
unnamed: LED7.2 (DOUT), LED8.4 (DIN)
unnamed: LED8.2 (DOUT), LED9.4 (DIN)
unnamed: LED9.2 (DOUT), LED10.4 (DIN)
unnamed: LED10.2 (DOUT), LED11.4 (DIN)
unnamed: LED11.2 (DOUT), LED12.4 (DIN)
unnamed: LED12.2 (DOUT), LED13.4 (DIN)
unnamed: LED13.2 (DOUT), LED14.4 (DIN)
unnamed: LED14.2 (DOUT), LED15.4 (DIN)
unnamed: LED15.2 (DOUT), LED16.4 (DIN)
unnamed: LED17.2 (DOUT), LED18.4 (DIN)
unnamed: LED18.2 (DOUT), LED19.4 (DIN)
unnamed: LED19.2 (DOUT), LED20.4 (DIN)
unnamed: LED20.2 (DOUT), LED21.4 (DIN)
unnamed: LED21.2 (DOUT), LED22.4 (DIN)
unnamed: LED22.2 (DOUT), LED23.4 (DIN)
unnamed: LED23.2 (DOUT), LED24.4 (DIN)
unnamed: LED24.2 (DOUT), LED25.4 (DIN)
unnamed: LED25.2 (DOUT), LED26.4 (DIN)
unnamed: LED26.2 (DOUT), LED27.4 (DIN)
unnamed: LED27.2 (DOUT), LED28.4 (DIN)
unnamed: LED28.2 (DOUT), LED29.4 (DIN)
unnamed: LED29.2 (DOUT), LED30.4 (DIN)
unnamed: LED30.2 (DOUT), LED31.4 (DIN)
unnamed: LED31.2 (DOUT), LED32.4 (DIN)
unnamed: LED32.2 (DOUT), LED33.4 (DIN)
unnamed: LED34.2 (DOUT), LED35.4 (DIN)
unnamed: LED35.2 (DOUT), LED36.4 (DIN)
unnamed: LED36.2 (DOUT), LED37.4 (DIN)
unnamed: LED37.2 (DOUT), LED38.4 (DIN)
unnamed: LED38.2 (DOUT), LED39.4 (DIN)
unnamed: LED39.2 (DOUT), LED40.4 (DIN)
unnamed: LED40.2 (DOUT), LED41.4 (DIN)
unnamed: LED41.2 (DOUT), LED42.4 (DIN)
unnamed: LED42.2 (DOUT), LED43.4 (DIN)
unnamed: LED43.2 (DOUT), LED44.4 (DIN)
unnamed: LED44.2 (DOUT), LED45.4 (DIN)
unnamed: LED45.2 (DOUT), LED46.4 (DIN)
unnamed: LED46.2 (DOUT), LED47.4 (DIN)
unnamed: LED47.2 (DOUT), LED48.4 (DIN)
unnamed: LED48.2 (DOUT), LED49.4 (DIN)
unnamed: LED49.2 (DOUT), LED50.4 (DIN)
unnamed: LED51.2 (DOUT), LED52.4 (DIN)
unnamed: LED52.2 (DOUT), LED53.4 (DIN)
unnamed: LED53.2 (DOUT), LED54.4 (DIN)
unnamed: LED54.2 (DOUT), LED55.4 (DIN)
unnamed: LED55.2 (DOUT), LED56.4 (DIN)
unnamed: LED56.2 (DOUT), LED57.4 (DIN)
unnamed: LED57.2 (DOUT), LED58.4 (DIN)
unnamed: LED58.2 (DOUT), LED59.4 (DIN)
unnamed: LED59.2 (DOUT), LED60.4 (DIN)
unnamed: LED60.2 (DOUT), LED61.4 (DIN)
unnamed: LED61.2 (DOUT), LED62.4 (DIN)
unnamed: LED62.2 (DOUT), LED63.4 (DIN)
unnamed: LED64.2 (DOUT), LED65.4 (DIN)
unnamed: LED65.2 (DOUT), LED66.4 (DIN)
unnamed: LED66.2 (DOUT), LED67.4 (DIN)
unnamed: LED67.2 (DOUT), LED68.4 (DIN)
unnamed: LED68.2 (DOUT), LED69.4 (DIN)
unnamed: LED69.2 (DOUT), LED70.4 (DIN)
unnamed: LED70.2 (DOUT), LED71.4 (DIN)
unnamed: LED71.2 (DOUT), LED72.4 (DIN)
unnamed: LED72.2 (DOUT), LED73.4 (DIN)
unnamed: LED73.2 (DOUT), LED74.4 (DIN)
unnamed: LED74.2 (DOUT), LED75.4 (DIN)
unnamed: LED75.2 (DOUT), LED76.4 (DIN)
unnamed: LED77.2 (DOUT), LED78.4 (DIN)
unnamed: LED78.2 (DOUT), LED79.4 (DIN)
unnamed: LED79.2 (DOUT), LED80.4 (DIN)
unnamed: LED80.2 (DOUT), LED81.4 (DIN)
unnamed: LED81.2 (DOUT), LED82.4 (DIN)
unnamed: LED82.2 (DOUT), LED83.4 (DIN)
unnamed: LED83.2 (DOUT), LED84.4 (DIN)
unnamed: LED84.2 (DOUT), LED85.4 (DIN)
unnamed: LED85.2 (DOUT), LED86.4 (DIN)
unnamed: LED86.2 (DOUT), LED87.4 (DIN)
unnamed: LEVEL_REGULATOR1.4 (B), R6.1

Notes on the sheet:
Boot mode entered thru shorting this pin to 3.3V
Main port
Port LED power
Switches
LDO+Level shifter
LEDs
ESD

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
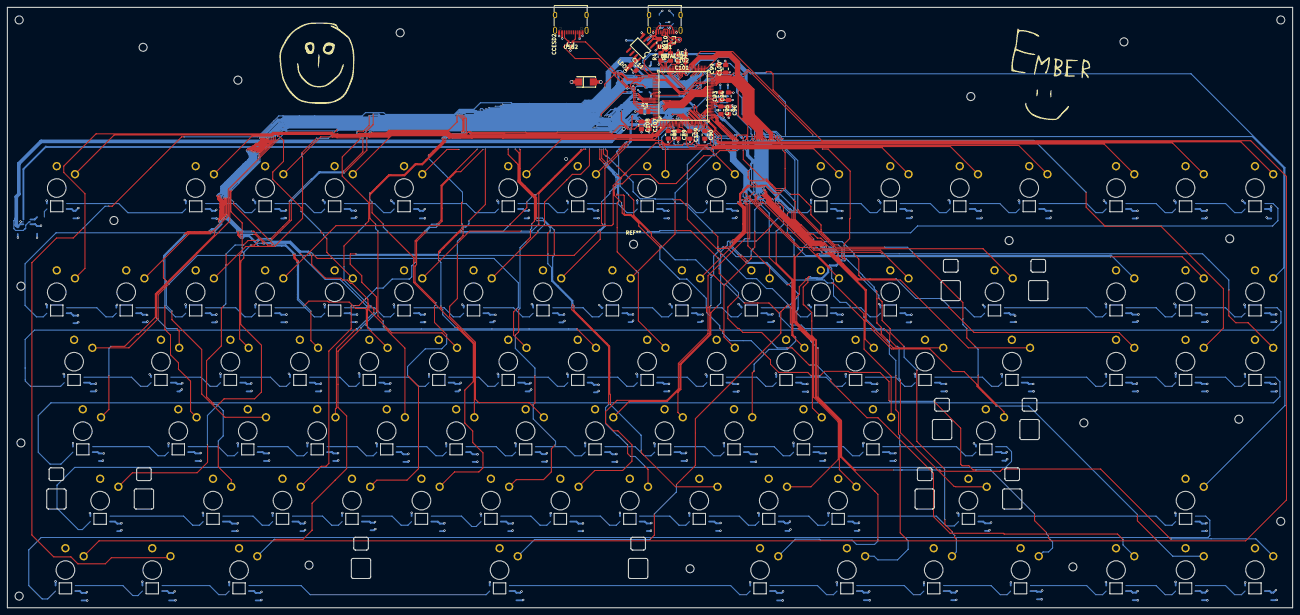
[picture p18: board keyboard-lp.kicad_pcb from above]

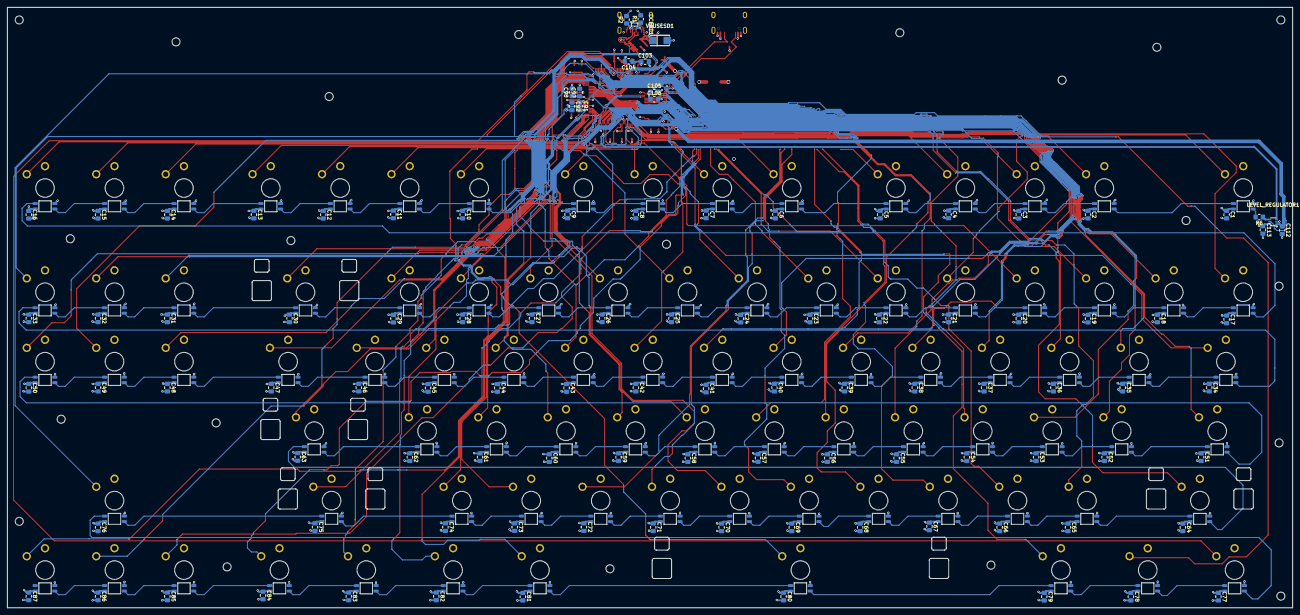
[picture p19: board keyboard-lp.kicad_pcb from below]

Board: 4 copper layers, 352.5 x 164.6 mm, 303 parts (190 on the bottom side), 190 nets.

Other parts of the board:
VBUSESD2: SMA6L5.0A; SMA_L4.3-W2.6-LS5.2-R-RD

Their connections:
GND: VBUSESD2.1 (A); also elsewhere on the board

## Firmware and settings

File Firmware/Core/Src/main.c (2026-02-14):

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
/* Includes ------------------------------------------------------------------*/
#include "main.h"
#include "usbpd.h"
#include "usb_device.h"

TIM_HandleTypeDef htim2;
DMA_HandleTypeDef hdma_tim2_ch1;

void SystemClock_Config(void);
static void MX_GPIO_Init(void);
static void MX_DMA_Init(void);
static void MX_TIM2_Init(void);
static void MX_UCPD1_Init(void);
/* USER CODE BEGIN 0 */
uint8_t keyboard_report[11];
// made with **help** of Google's NotebookLM
#define NUM_LEDS 87
#define BITS_PER_LED 24
#define PWM_HI 130
#define PWM_LO 43
uint32_t led_buffer[NUM_LEDS * BITS_PER_LED]; // 87 diodes, 24 bits per diode 1 byte per color
/* USER CODE END 0 */

/**
  * @brief  The application entry point.
  * @retval int
  */
int main(void)
{

  /* MCU Configuration--------------------------------------------------------*/

  /* Reset of all peripherals, Initializes the Flash interface and the Systick. */
  HAL_Init();

  /* Configure the system clock */
  SystemClock_Config();

  /* Initialize all configured peripherals */
  MX_GPIO_Init();
  MX_DMA_Init();
  MX_TIM2_Init();
  MX_UCPD1_Init();
  MX_USB_Device_Init();
  /* USER CODE BEGIN 2 */
4
  /* USER CODE END 2 */

  /* USBPD initialisation ---------------------------------*/
  MX_USBPD_Init();

  /* Infinite loop */
  /* USER CODE BEGIN WHILE */
  while (1)
  {
    /* USER CODE END WHILE */
    USBPD_DPM_Run();

    /* USER CODE BEGIN 3 */
    //made with **help** of chatgpt cuz it is my first usb-hid project in stm32cube and not kmk
    for(int i=0; i<11; i++) keyboard_report[i] = 0;

    //check every gpio pin
    if(HAL_GPIO_ReadPin(GPIOE, ESC_1_Pin) == GPIO_PIN_RESET) keyboard_report[0] |= (1 << 0);
    if(HAL_GPIO_ReadPin(GPIOE, F1_2_Pin) == GPIO_PIN_RESET) keyboard_report[0] |= (1 << 1);
    if(HAL_GPIO_ReadPin(GPIOE, F2_3_Pin) == GPIO_PIN_RESET) keyboard_report[0] |= (1 << 2);
    if(HAL_GPIO_ReadPin(GPIOE, F3_4_Pin) == GPIO_PIN_RESET) keyboard_report[0] |= (1 << 3);
    if(HAL_GPIO_ReadPin(GPIOE, F4_5_Pin) == GPIO_PIN_RESET) keyboard_report[0] |= (1 << 4);
    if(HAL_GPIO_ReadPin(GPIOE, F5_6_Pin) == GPIO_PIN_RESET) keyboard_report[0] |= (1 << 5);
    if(HAL_GPIO_ReadPin(GPIOE, F6_7_Pin) == GPIO_PIN_RESET) keyboard_report[0] |= (1 << 6);
    if(HAL_GPIO_ReadPin(GPIOE, F7_8_Pin) == GPIO_PIN_RESET) keyboard_report[0] |= (1 << 7);
    if(HAL_GPIO_ReadPin(GPIOE, F8_9_Pin) == GPIO_PIN_RESET) keyboard_report[1] |= (1 << 0);
    if(HAL_GPIO_ReadPin(GPIOE, F9_10_Pin) == GPIO_PIN_RESET) keyboard_report[1] |= (1 << 1);
    if(HAL_GPIO_ReadPin(GPIOE, F10_11_Pin) == GPIO_PIN_RESET) keyboard_report[1] |= (1 << 2);
    if(HAL_GPIO_ReadPin(GPIOE, F11_12_Pin) == GPIO_PIN_RESET) keyboard_report[1] |= (1 << 3);
    if(HAL_GPIO_ReadPin(GPIOE, F12_13_Pin) == GPIO_PIN_RESET) keyboard_report[1] |= (1 << 4);
    if(HAL_GPIO_ReadPin(GPIOE, PrtSc_14_Pin) == GPIO_PIN_RESET) keyboard_report[1] |= (1 << 5);
    if(HAL_GPIO_ReadPin(GPIOE, ScrLk_15_Pin) == GPIO_PIN_RESET) keyboard_report[1] |= (1 << 6);
    if(HAL_GPIO_ReadPin(GPIOE, Pause_16_Pin) == GPIO_PIN_RESET) keyboard_report[1] |= (1 << 7);
    if(HAL_GPIO_ReadPin(GPIOE, Grave_17_Pin) == GPIO_PIN_RESET) keyboard_report[2] |= (1 << 0);
    if(HAL_GPIO_ReadPin(GPIOE, Key1_18_Pin) == GPIO_PIN_RESET) keyboard_report[2] |= (1 << 1);
    if(HAL_GPIO_ReadPin(GPIOE, Key2_19_Pin) == GPIO_PIN_RESET) keyboard_report[2] |= (1 << 2);
    if(HAL_GPIO_ReadPin(GPIOE, Key3_20_Pin) == GPIO_PIN_RESET) keyboard_report[2] |= (1 << 3);
    if(HAL_GPIO_ReadPin(GPIOE, Key4_21_Pin) == GPIO_PIN_RESET) keyboard_report[2] |= (1 << 4);
    if(HAL_GPIO_ReadPin(GPIOE, Key5_22_Pin) == GPIO_PIN_RESET) keyboard_report[2] |= (1 << 5);
    if(HAL_GPIO_ReadPin(GPIOE, Key6_23_Pin) == GPIO_PIN_RESET) keyboard_report[2] |= (1 << 6);
    if(HAL_GPIO_ReadPin(GPIOE, Key7_24_Pin) == GPIO_PIN_RESET) keyboard_report[2] |= (1 << 7);
    if(HAL_GPIO_ReadPin(GPIOE, Key8_25_Pin) == GPIO_PIN_RESET) keyboard_report[3] |= (1 << 0);
    if(HAL_GPIO_ReadPin(GPIOE, Key9_26_Pin) == GPIO_PIN_RESET) keyboard_report[3] |= (1 << 1);
    if(HAL_GPIO_ReadPin(GPIOE, Key0_27_Pin) == GPIO_PIN_RESET) keyboard_report[3] |= (1 << 2);
    if(HAL_GPIO_ReadPin(GPIOE, Minus_28_Pin) == GPIO_PIN_RESET) keyboard_report[3] |= (1 << 3);
    if(HAL_GPIO_ReadPin(GPIOE, Plus_29_Pin) == GPIO_PIN_RESET) keyboard_report[3] |= (1 << 4);
    if(HAL_GPIO_ReadPin(GPIOE, Backspace_30_Pin) == GPIO_PIN_RESET) keyboard_report[3] |= (1 << 5);
    if(HAL_GPIO_ReadPin(GPIOE, Insert_31_Pin) == GPIO_PIN_RESET) keyboard_report[3] |= (1 << 6);
    if(HAL_GPIO_ReadPin(GPIOE, Home_32_Pin) == GPIO_PIN_RESET) keyboard_report[3] |= (1 << 7);
    if(HAL_GPIO_ReadPin(GPIOE, PgUp_33_Pin) == GPIO_PIN_RESET) keyboard_report[4] |= (1 << 0);
    if(HAL_GPIO_ReadPin(GPIOE, Tab_34_Pin) == GPIO_PIN_RESET) keyboard_report[4] |= (1 << 1);
    if(HAL_GPIO_ReadPin(GPIOE, Q_35_Pin) == GPIO_PIN_RESET) keyboard_report[4] |= (1 << 2);
    if(HAL_GPIO_ReadPin(GPIOE, W_36_Pin) == GPIO_PIN_RESET) keyboard_report[4] |= (1 << 3);
    if(HAL_GPIO_ReadPin(GPIOE, E_37_Pin) == GPIO_PIN_RESET) keyboard_report[4] |= (1 << 4);
    if(HAL_GPIO_ReadPin(GPIOE, R_38_Pin) == GPIO_PIN_RESET) keyboard_report[4] |= (1 << 5);
    if(HAL_GPIO_ReadPin(GPIOE, T_39_Pin) == GPIO_PIN_RESET) keyboard_report[4] |= (1 << 6);
    if(HAL_GPIO_ReadPin(GPIOE, Y_40_Pin) == GPIO_PIN_RESET) keyboard_report[4] |= (1 << 7);
    if(HAL_GPIO_ReadPin(GPIOE, U_41_Pin) == GPIO_PIN_RESET) keyboard_report[5] |= (1 << 0);
    if(HAL_GPIO_ReadPin(GPIOE, I_42_Pin) == GPIO_PIN_RESET) keyboard_report[5] |= (1 << 1);
    if(HAL_GPIO_ReadPin(GPIOE, O_43_Pin) == GPIO_PIN_RESET) keyboard_report[5] |= (1 << 2);
    if(HAL_GPIO_ReadPin(GPIOE, P_44_Pin) == GPIO_PIN_RESET) keyboard_report[5] |= (1 << 3);
    if(HAL_GPIO_ReadPin(GPIOE, Key__45_Pin) == GPIO_PIN_RESET) keyboard_report[5] |= (1 << 4);
    if(HAL_GPIO_ReadPin(GPIOE, Key__46_Pin) == GPIO_PIN_RESET) keyboard_report[5] |= (1 << 5);
    if(HAL_GPIO_ReadPin(GPIOE, Key__47_Pin) == GPIO_PIN_RESET) keyboard_report[5] |= (1 << 6);
    if(HAL_GPIO_ReadPin(GPIOE, Delete_48_Pin) == GPIO_PIN_RESET) keyboard_report[5] |= (1 << 7);
    if(HAL_GPIO_ReadPin(GPIOE, End_49_Pin) == GPIO_PIN_RESET) keyboard_report[6] |= (1 << 0);
    if(HAL_GPIO_ReadPin(GPIOE, PgDn_50_Pin) == GPIO_PIN_RESET) keyboard_report[6] |= (1 << 1);
    if(HAL_GPIO_ReadPin(GPIOE, Caps_51_Pin) == GPIO_PIN_RESET) keyboard_report[6] |= (1 << 2);
    if(HAL_GPIO_ReadPin(GPIOE, A_52_Pin) == GPIO_PIN_RESET) keyboard_report[6] |= (1 << 3);
    if(HAL_GPIO_ReadPin(GPIOE, S_53_Pin) == GPIO_PIN_RESET) keyboard_report[6] |= (1 << 4);
    if(HAL_GPIO_ReadPin(GPIOE, D_54_Pin) == GPIO_PIN_RESET) keyboard_report[6] |= (1 << 5);
    if(HAL_GPIO_ReadPin(GPIOE, F_55_Pin) == GPIO_PIN_RESET) keyboard_report[6] |= (1 << 6);
    if(HAL_GPIO_ReadPin(GPIOE, G_56_Pin) == GPIO_PIN_RESET) keyboard_report[6] |= (1 << 7);
    if(HAL_GPIO_ReadPin(GPIOE, H_57_Pin) == GPIO_PIN_RESET) keyboard_report[7] |= (1 << 0);
    if(HAL_GPIO_ReadPin(GPIOE, J_58_Pin) == GPIO_PIN_RESET) keyboard_report[7] |= (1 << 1);
    if(HAL_GPIO_ReadPin(GPIOE, K_59_Pin) == GPIO_PIN_RESET) keyboard_report[7] |= (1 << 2);
    if(HAL_GPIO_ReadPin(GPIOE, L_60_Pin) == GPIO_PIN_RESET) keyboard_report[7] |= (1 << 3);
    if(HAL_GPIO_ReadPin(GPIOE, Key__61_Pin) == GPIO_PIN_RESET) keyboard_report[7] |= (1 << 4);
    if(HAL_GPIO_ReadPin(GPIOE, Key__62_Pin) == GPIO_PIN_RESET) keyboard_report[7] |= (1 << 5);
    if(HAL_GPIO_ReadPin(GPIOE, Enter_63_Pin) == GPIO_PIN_RESET) keyboard_report[7] |= (1 << 6);
    if(HAL_GPIO_ReadPin(GPIOE, LShift_64_Pin) == GPIO_PIN_RESET) keyboard_report[7] |= (1 << 7);
    if(HAL_GPIO_ReadPin(GPIOE, Z_65_Pin) == GPIO_PIN_RESET) keyboard_report[8] |= (1 << 0);
    if(HAL_GPIO_ReadPin(GPIOE, X_66_Pin) == GPIO_PIN_RESET) keyboard_report[8] |= (1 << 1);
    if(HAL_GPIO_ReadPin(GPIOE, C_67_Pin) == GPIO_PIN_RESET) keyboard_report[8] |= (1 << 2);
    if(HAL_GPIO_ReadPin(GPIOE, V_68_Pin) == GPIO_PIN_RESET) keyboard_report[8] |= (1 << 3);
    if(HAL_GPIO_ReadPin(GPIOE, B_69_Pin) == GPIO_PIN_RESET) keyboard_report[8] |= (1 << 4);
    if(HAL_GPIO_ReadPin(GPIOE, N_70_Pin) == GPIO_PIN_RESET) keyboard_report[8] |= (1 << 5);
    if(HAL_GPIO_ReadPin(GPIOE, M_71_Pin) == GPIO_PIN_RESET) keyboard_report[8] |= (1 << 6);
    if(HAL_GPIO_ReadPin(GPIOE, Key__72_Pin) == GPIO_PIN_RESET) keyboard_report[8] |= (1 << 7);
    if(HAL_GPIO_ReadPin(GPIOE, Key__73_Pin) == GPIO_PIN_RESET) keyboard_report[9] |= (1 << 0);
    if(HAL_GPIO_ReadPin(GPIOE, Key__74_Pin) == GPIO_PIN_RESET) keyboard_report[9] |= (1 << 1);
    if(HAL_GPIO_ReadPin(GPIOE, RShift_75_Pin) == GPIO_PIN_RESET) keyboard_report[9] |= (1 << 2);
    if(HAL_GPIO_ReadPin(GPIOE, Up_76_Pin) == GPIO_PIN_RESET) keyboard_report[9] |= (1 << 3);
    if(HAL_GPIO_ReadPin(GPIOE, LCtrl_77_Pin) == GPIO_PIN_RESET) keyboard_report[9] |= (1 << 4);
    if(HAL_GPIO_ReadPin(GPIOE, Win_78_Pin) == GPIO_PIN_RESET) keyboard_report[9] |= (1 << 5);
    if(HAL_GPIO_ReadPin(GPIOE, LAlt_79_Pin) == GPIO_PIN_RESET) keyboard_report[9] |= (1 << 6);
    if(HAL_GPIO_ReadPin(GPIOE, Space__80_Pin) == GPIO_PIN_RESET) keyboard_report[9] |= (1 << 7);
    if(HAL_GPIO_ReadPin(GPIOE, RAlt_81_Pin) == GPIO_PIN_RESET) keyboard_report[10] |= (1 << 0);
    if(HAL_GPIO_ReadPin(GPIOE, Menu_82_Pin) == GPIO_PIN_RESET) keyboard_report[10] |= (1 << 1);
    if(HAL_GPIO_ReadPin(GPIOE, Fn_83_Pin) == GPIO_PIN_RESET) keyboard_report[10] |= (1 << 2);
    if(HAL_GPIO_ReadPin(GPIOE, RCtrl_84_Pin) == GPIO_PIN_RESET) keyboard_report[10] |= (1 << 3);
    if(HAL_GPIO_ReadPin(GPIOE, Left_85_Pin) == GPIO_PIN_RESET) keyboard_report[10] |= (1 << 4);
    if(HAL_GPIO_ReadPin(GPIOE, Down_86_Pin) == GPIO_PIN_RESET) keyboard_report[10] |= (1 << 5);
    if(HAL_GPIO_ReadPin(GPIOE, Right_87_Pin) == GPIO_PIN_RESET) keyboard_report[10] |= (1 << 6);

    // made with **help** of chatgpt and notebooklm too, help = he explained how to do it, i made the code, verified with him if it will work, and he confirmed or said it wont and said what to fix
    uint32_t color_grb;
    for(int i = 0; i < NUM_LEDS; i++) {
    	int byte = i / 8;
    	int bit = i % 8;
    	if(keyboard_report[byte] & (1 << bit)) {
    		// key pressed -> led under it goes to red
    		color_grb = (0x00 << 16) | (0xFF << 8) | 0x00;
    	} else {
    		// other leds -> white, 70% of white as per producer words
    		color_grb = (178 << 16) | (178 << 8) | 178;
    	}


		for(int b = 0; b < BITS_PER_LED; b++) {
			if(color_grb & (1 << (23 - b))) {
				led_buffer[i * BITS_PER_LED + b] = PWM_HI;
			} else {
				led_buffer[i * BITS_PER_LED + b] = PWM_LO;
			}
		}
    }

    HAL_TIM_PWM_Start_DMA(&htim2, TIM_CHANNEL_1, led_buffer, NUM_LEDS * BITS_PER_LED);

    //send report
    USBD_HID_SendReport(&hUsbDeviceFS, keyboard_report, 11);

    //delay
    HAL_Delay(4);

  }
  /* USER CODE END 3 */
}

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
/* USER CODE BEGIN 4 */
void HAL_TIM_PWM_PulseFinishedCallback(TIM_HandleTypeDef *htim) {
    if (htim->Instance == TIM2) {
        HAL_TIM_PWM_Stop_DMA(&htim2, TIM_CHANNEL_1);
    }
}
/* USER CODE END 4 */
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


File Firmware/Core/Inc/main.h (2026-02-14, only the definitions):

#define LED_PWM_ARR 179
#define LED_PWM_BIT_0 43
#define LED_PWM_BIT_1 86
#define ESC_1_Pin GPIO_PIN_2
#define ESC_1_GPIO_Port GPIOE
#define F1_2_Pin GPIO_PIN_3
#define F1_2_GPIO_Port GPIOE
#define F2_3_Pin GPIO_PIN_4
#define F2_3_GPIO_Port GPIOE
#define F3_4_Pin GPIO_PIN_5
#define F3_4_GPIO_Port GPIOE
#define F4_5_Pin GPIO_PIN_6
#define F4_5_GPIO_Port GPIOE
#define F5_6_Pin GPIO_PIN_13
#define F5_6_GPIO_Port GPIOC
#define F6_7_Pin GPIO_PIN_14
#define F6_7_GPIO_Port GPIOC
#define F7_8_Pin GPIO_PIN_15
#define F7_8_GPIO_Port GPIOC
#define F8_9_Pin GPIO_PIN_3
#define F8_9_GPIO_Port GPIOF
#define F9_10_Pin GPIO_PIN_4
#define F9_10_GPIO_Port GPIOF
#define F10_11_Pin GPIO_PIN_5
#define F10_11_GPIO_Port GPIOF
#define F11_12_Pin GPIO_PIN_7
#define F11_12_GPIO_Port GPIOF
#define F12_13_Pin GPIO_PIN_8
#define F12_13_GPIO_Port GPIOF
#define PrtSc_14_Pin GPIO_PIN_9
#define PrtSc_14_GPIO_Port GPIOF
#define ScrLk_15_Pin GPIO_PIN_10
#define ScrLk_15_GPIO_Port GPIOF
#define Pause_16_Pin GPIO_PIN_0
#define Pause_16_GPIO_Port GPIOF
#define Grave_17_Pin GPIO_PIN_1
#define Grave_17_GPIO_Port GPIOF
#define Key1_18_Pin GPIO_PIN_0
#define Key1_18_GPIO_Port GPIOC
#define Key2_19_Pin GPIO_PIN_1
#define Key2_19_GPIO_Port GPIOC
#define Key3_20_Pin GPIO_PIN_2
#define Key3_20_GPIO_Port GPIOC
#define Key4_21_Pin GPIO_PIN_3
#define Key4_21_GPIO_Port GPIOC
#define Key5_22_Pin GPIO_PIN_2
#define Key5_22_GPIO_Port GPIOF
#define Key6_23_Pin GPIO_PIN_1
#define Key6_23_GPIO_Port GPIOA
#define Key7_24_Pin GPIO_PIN_2
#define Key7_24_GPIO_Port GPIOA
#define Key8_25_Pin GPIO_PIN_3
#define Key8_25_GPIO_Port GPIOA
#define Key9_26_Pin GPIO_PIN_4
#define Key9_26_GPIO_Port GPIOA
#define Key0_27_Pin GPIO_PIN_5
#define Key0_27_GPIO_Port GPIOA
#define Minus_28_Pin GPIO_PIN_6
#define Minus_28_GPIO_Port GPIOA
#define Plus_29_Pin GPIO_PIN_7
#define Plus_29_GPIO_Port GPIOA
#define Backspace_30_Pin GPIO_PIN_4
#define Backspace_30_GPIO_Port GPIOC
#define Insert_31_Pin GPIO_PIN_5
#define Insert_31_GPIO_Port GPIOC
#define Home_32_Pin GPIO_PIN_0
#define Home_32_GPIO_Port GPIOB
#define PgUp_33_Pin GPIO_PIN_1
#define PgUp_33_GPIO_Port GPIOB
#define Tab_34_Pin GPIO_PIN_2
#define Tab_34_GPIO_Port GPIOB
#define Q_35_Pin GPIO_PIN_11
#define Q_35_GPIO_Port GPIOF
#define W_36_Pin GPIO_PIN_12
#define W_36_GPIO_Port GPIOF
#define E_37_Pin GPIO_PIN_13
#define E_37_GPIO_Port GPIOF
#define R_38_Pin GPIO_PIN_14
#define R_38_GPIO_Port GPIOF
#define T_39_Pin GPIO_PIN_15
#define T_39_GPIO_Port GPIOF
#define Y_40_Pin GPIO_PIN_7
#define Y_40_GPIO_Port GPIOE
#define U_41_Pin GPIO_PIN_8
#define U_41_GPIO_Port GPIOE
#define I_42_Pin GPIO_PIN_9
#define I_42_GPIO_Port GPIOE
#define O_43_Pin GPIO_PIN_10
#define O_43_GPIO_Port GPIOE
#define P_44_Pin GPIO_PIN_11
#define P_44_GPIO_Port GPIOE
#define Key__45_Pin GPIO_PIN_12
#define Key__45_GPIO_Port GPIOE
#define Key__46_Pin GPIO_PIN_13
#define Key__46_GPIO_Port GPIOE
#define Key__47_Pin GPIO_PIN_14
#define Key__47_GPIO_Port GPIOE
#define Delete_48_Pin GPIO_PIN_15
#define Delete_48_GPIO_Port GPIOE
#define End_49_Pin GPIO_PIN_10
#define End_49_GPIO_Port GPIOB
#define PgDn_50_Pin GPIO_PIN_11
#define PgDn_50_GPIO_Port GPIOB
#define Caps_51_Pin GPIO_PIN_12
#define Caps_51_GPIO_Port GPIOB
#define A_52_Pin GPIO_PIN_13
#define A_52_GPIO_Port GPIOB
#define S_53_Pin GPIO_PIN_14
#define S_53_GPIO_Port GPIOB
#define D_54_Pin GPIO_PIN_15
#define D_54_GPIO_Port GPIOB
#define F_55_Pin GPIO_PIN_8
#define F_55_GPIO_Port GPIOD
#define G_56_Pin GPIO_PIN_9
#define G_56_GPIO_Port GPIOD
#define H_57_Pin GPIO_PIN_10
#define H_57_GPIO_Port GPIOD
#define J_58_Pin GPIO_PIN_11
#define J_58_GPIO_Port GPIOD
#define K_59_Pin GPIO_PIN_12
#define K_59_GPIO_Port GPIOD
#define L_60_Pin GPIO_PIN_13
#define L_60_GPIO_Port GPIOD
#define Key__61_Pin GPIO_PIN_14
#define Key__61_GPIO_Port GPIOD
#define Key__62_Pin GPIO_PIN_15
#define Key__62_GPIO_Port GPIOD
#define Enter_63_Pin GPIO_PIN_6
#define Enter_63_GPIO_Port GPIOC
#define LShift_64_Pin GPIO_PIN_7
#define LShift_64_GPIO_Port GPIOC
#define Z_65_Pin GPIO_PIN_0
#define Z_65_GPIO_Port GPIOG
#define X_66_Pin GPIO_PIN_1
#define X_66_GPIO_Port GPIOG
#define C_67_Pin GPIO_PIN_2
#define C_67_GPIO_Port GPIOG
#define V_68_Pin GPIO_PIN_3
#define V_68_GPIO_Port GPIOG
#define B_69_Pin GPIO_PIN_4
#define B_69_GPIO_Port GPIOG
#define N_70_Pin GPIO_PIN_8
#define N_70_GPIO_Port GPIOC
#define M_71_Pin GPIO_PIN_9
#define M_71_GPIO_Port GPIOC
#define Key__72_Pin GPIO_PIN_8
#define Key__72_GPIO_Port GPIOA
#define Key__73_Pin GPIO_PIN_9
#define Key__73_GPIO_Port GPIOA
#define Key__74_Pin GPIO_PIN_10
#define Key__74_GPIO_Port GPIOA
#define RShift_75_Pin GPIO_PIN_13
#define RShift_75_GPIO_Port GPIOA
#define Up_76_Pin GPIO_PIN_6
#define Up_76_GPIO_Port GPIOF
#define LCtrl_77_Pin GPIO_PIN_14
#define LCtrl_77_GPIO_Port GPIOA
#define Win_78_Pin GPIO_PIN_15
#define Win_78_GPIO_Port GPIOA
#define LAlt_79_Pin GPIO_PIN_10
#define LAlt_79_GPIO_Port GPIOC
#define Space_80_Pin GPIO_PIN_11
#define Space_80_GPIO_Port GPIOC
#define RAlt_81_Pin GPIO_PIN_12
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

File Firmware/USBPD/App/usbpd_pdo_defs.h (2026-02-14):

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

#ifndef __USBPD_PDO_DEF_H_
#define __USBPD_PDO_DEF_H_

#ifdef __cplusplus
 extern "C" {
#endif

/* Includes ------------------------------------------------------------------*/
#include "usbpd_def.h"

/* Define   ------------------------------------------------------------------*/
#define PORT0_NB_SOURCEPDO         0U   /* Number of Source PDOs (applicable for port 0)   */
#define PORT0_NB_SINKPDO           1U   /* Number of Sink PDOs (applicable for port 0)     */
#define PORT1_NB_SOURCEPDO         0U   /* Number of Source PDOs (applicable for port 1)   */
#define PORT1_NB_SINKPDO           0U   /* Number of Sink PDOs (applicable for port 1)     */

/* Exported typedef ----------------------------------------------------------*/

/* USER CODE BEGIN typedef */
/**
  * @brief  USBPD Port PDO Structure definition
  *
  */
/* USER CODE END typedef */

/* Exported define -----------------------------------------------------------*/

/* USER CODE BEGIN Exported_Define */

#define USBPD_CORE_PDO_SRC_FIXED_MAX_CURRENT 3
#define USBPD_CORE_PDO_SNK_FIXED_MAX_CURRENT 1500

/* USER CODE END Exported_Define */

/* Exported constants --------------------------------------------------------*/

/* Exported macro ------------------------------------------------------------*/

/* Exported variables --------------------------------------------------------*/

#ifndef __USBPD_PWR_IF_C
extern uint32_t PORT0_PDO_ListSRC[USBPD_MAX_NB_PDO];
extern uint32_t PORT0_PDO_ListSNK[USBPD_MAX_NB_PDO];
#else
/* Definition of Source PDO for Port 0 */
uint32_t PORT0_PDO_ListSRC[USBPD_MAX_NB_PDO] =
{
  /* PDO 1 */ (0x00000000U),

  /* PDO 2 */ (0x00000000U),

  /* PDO 3 */ (0x00000000U),

  /* PDO 4 */ (0x00000000U),

  /* PDO 5 */ (0x00000000U),

  /* PDO 6 */ (0x00000000U),

  /* PDO 7 */ (0x00000000U),

};

/* Definition of Sink PDO for Port 0 */
uint32_t PORT0_PDO_ListSNK[USBPD_MAX_NB_PDO] =
{

  /* PDO 1 */
  (
    USBPD_PDO_TYPE_FIXED                 | /* Fixed supply PDO            */

    USBPD_PDO_SNK_FIXED_SET_VOLTAGE(5000U)         | /* Voltage in mV               */
    USBPD_PDO_SNK_FIXED_SET_OP_CURRENT(3000U)     | /* Operating current in  mA            */

    /* Common definitions applicable to all PDOs, defined only in PDO 1 */
    USBPD_PDO_SNK_FIXED_FRS_NOT_SUPPORTED          | /* Fast Role Swap				 */
    USBPD_PDO_SNK_FIXED_DRD_NOT_SUPPORTED          | /* Dual-Role Data              */
    USBPD_PDO_SNK_FIXED_USBCOMM_NOT_SUPPORTED      | /* USB Communications          */
    USBPD_PDO_SNK_FIXED_EXT_POWER_NOT_AVAILABLE    | /* External Power              */
    USBPD_PDO_SNK_FIXED_HIGHERCAPAB_NOT_SUPPORTED   | /* Higher Capability           */
    USBPD_PDO_SNK_FIXED_DRP_NOT_SUPPORTED            /* Dual-Role Power             */
  ),

  /* PDO 2 */ (0x00000000U),

  /* PDO 3 */ (0x00000000U),

  /* PDO 4 */ (0x00000000U),

  /* PDO 5 */ (0x00000000U),

  /* PDO 6 */ (0x00000000U),

  /* PDO 7 */ (0x00000000U),
};

#endif

/* Exported functions --------------------------------------------------------*/

#ifdef __cplusplus
}
#endif

#endif /* __USBPD_PDO_DEF_H_ */

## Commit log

2026-02-11 push gerbers
2026-02-13 Update 3d model and required footprints
    [pcb-3d.step]
2026-02-13 Made and added 3d case
    [bottom_case_1.step, bottom_case_2.step, case.step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]
2026-02-14 Added usb ports to pcb step
    [pcb-3d.step]
2026-02-14 Updated case 3d model to include usb ports and added photos of 3d models
    [case.step]
2026-02-14 Added f3d files
    [bottom_case.f3d, pcb-3d v2.f3d, top_plate.f3d]
2026-02-14 Added README.md
    [BOM.csv]
2026-02-14 Added prototype firmware and connected ground planes together on pcb
    [bottom_case.f3d, bottom_case_1.step, bottom_case_2.step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]
2026-02-14 Removed pcb backup folder
2026-02-14 Updated PCB screenshot to reflect connected gnd planes and set zone visibility to higher number
2026-02-22 Added siklscreen quote unquote art, i am not an artist okay?
    [keyboard-lp.kicad_pcb]
2026-02-23 Added art in the empty space on case
    [case.step, top_plate.f3d, top_plate_1.step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]

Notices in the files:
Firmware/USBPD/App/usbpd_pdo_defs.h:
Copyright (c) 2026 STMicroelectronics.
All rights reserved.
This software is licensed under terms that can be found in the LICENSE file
